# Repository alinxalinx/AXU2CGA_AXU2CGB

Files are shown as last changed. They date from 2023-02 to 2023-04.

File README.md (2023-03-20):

# Xilinx Zynq Ultrascale+ MPSoC Series Development Board AXU2CGA/AXU2CGB

## Introduction to Development Board

The PS side of the AXU2CGA mounts two DDR4 chips (totaling 1GB, 32bit) and one 256Mb QSPI FLASH. The PS side of the AXU2CGB mounts four DDR4 chips (totaling 2GB, 64bit), one 8GB eMMC FLASH memory chip, and one 256Mb FLASH memory chip
The peripheral interface of QSPI FLASH includes 1 MINI DP interface, 4 USB 3.0 interfaces, 1 Gigabit Ethernet interface, 1 USB serial port, 1 PCIE interface, 1 TF card interface, 2 40-pin expansion ports, 2 MIPI interfaces, and key LEDs. Both development boards use XCZU2CG-1SFVC784E chips.

## Key Characteristics

1. Two Micron ddr chips (AXU2CGA), four Micron ddr chips (AXU2CGB), 256MX16bit
2. One 256Mbit QUAD-SPI FLASH chip, one 8GB emmc flash chip (AXU2CGB)
3. 1 EEPROM (ps)
4. 1-channel DP output interface, mini DP (ps), maximum support 4kx2k@30fps Output
5. 4-way USB 3.0 interface, USB (ps), speed 5.0Gbps, flat USB interface (USB Type A)
6. 1-way Gigabit Ethernet interface, jl2121, connected to ps, rgmii interface
7. 1 uart to usb connection to ps
8. 1 Micro SD card holder (ps)
9. One PCIEx1 slot with a speed of 5Gbps
10. Two 40-pin expansion ports, 2.54mm spacing, one 5v, two 3.3v, three gnd, and 34 IO ports. The IO level standard of the expansion port is 3.3V
11. 1-way mipi interface (pl), 15PIN FPC connector, 2 lane data, 1 pair of clocks
12. 1 RTC real-time clock, 32.768KHz passive clock (ps)
13. Four LED lights, user indicator lights, and one reset button
14. One 4-bit dial switch, and the board supports four startup modes
15. Size 85x91.11mm
16. Power supply 12v/3A

# AXU2CGA/AXU2CGB Demo Project
## Description
This is vivado factory demo project for ALINX board.
## Requirement
* Vivado 2020.1
* AXU2CGA/AXU2CGB Development Board
## Create Vivado Project
* Download recent release ZIP archive.
* Create new project folder.
* Extract the download ZIP to the new project folder.
* For different development board, please open **\<archive extracted location\>/vivado/auto_create_project/create_project.tcl**， line 6 or 7,
Choose one projName and save.

There are two methods to create vivado project as below:
### Create Vivado Project in Vivado tcl console
1. Open Vivado software and switch to "**auto_create_project**" path with **cd** command and **Enter**
```
cd \<archive extracted location\>/vivado/auto_create_project
```
2. Type **source ./create_project.tcl** and **Enter**
```
source ./create_project.tcl
```

### Create Vivado Project using bat
1. In "**auto_create_project**" folder, there is "**create_project.bat**", open it in edit mode, and change to your own vivado software installation path. Save and close.
```
CALL E:\XilinxVitis\Vivado\2020.1\bin\vivado.bat -mode batch -source create_project.tcl
PAUSE
```
2. Double click bat file in Windows environment

For more information, please post on the [ALINX Website] (https://www.alinx.com/en).

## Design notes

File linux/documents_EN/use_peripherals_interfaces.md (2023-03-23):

[Back to Home](../)
## Use the interfaces and peripherals on the development board in LINUX

---
- These interfaces and peripherals are available on the AXU2CGA and AXU2CGB development boards: 
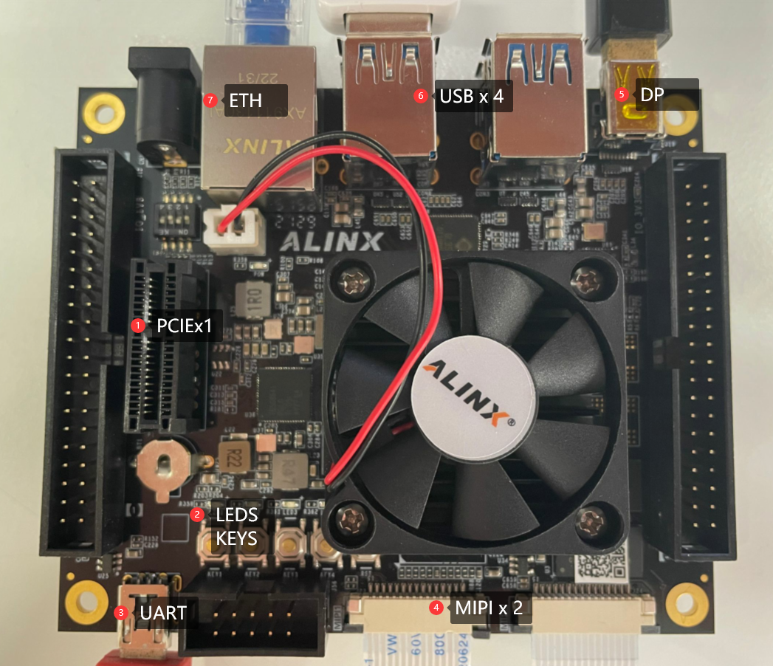
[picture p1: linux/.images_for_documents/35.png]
\
①PCIEx1\
②LEDS、KEYS\
③UART\
④MIPI x 2\
⑤DP
⑥USB x 4\
⑦ETH\
⑧EMMC(Not visible in the figure, AXU2CGB only)\
⑨EEPROM(Not visible in the figure)\
⑩QSPI FLASH(Not visible in the figure)\
⑪RTC(Not visible in the figure)\
PS : In the Linux system on the development board made earlier, I integrated some shell scripts in path *~/shells_for_testing_peripheral_devices/*, which are used to test these interfaces and peripherals. You can also refer to these shell scripts to use these interfaces and peripherals:\
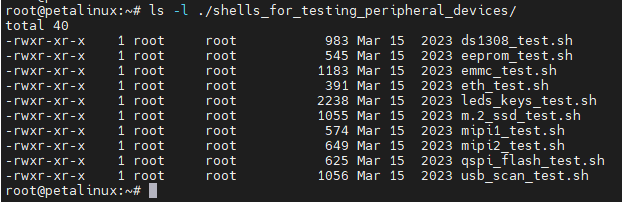
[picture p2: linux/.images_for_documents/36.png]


---
### ①PCIEx1
#### 1.1What is PCIex1
PCIe (Peripheral Component Interconnect Express) is a high-speed data transmission interface used to connect external devices and expansion cards on the motherboard. It is a serial interface. Compared with PCI interface, it has higher bandwidth and better scalability.\
PCIe slots are usually x1, x4, x8 or x16 in size, representing different bandwidth and transmission rates. The bandwidth of the PCIex1 bus interface is 250MB/s.\
PCIex1 can be used as an expansion card interface to add additional expansion cards, such as SSD controllers.
#### 1.2How to use PCIex1 in Linux
Take the SSD expansion card as an example, connect the SSD expansion card on the PCIex1 interface of the development board (please do not operate with power)：\
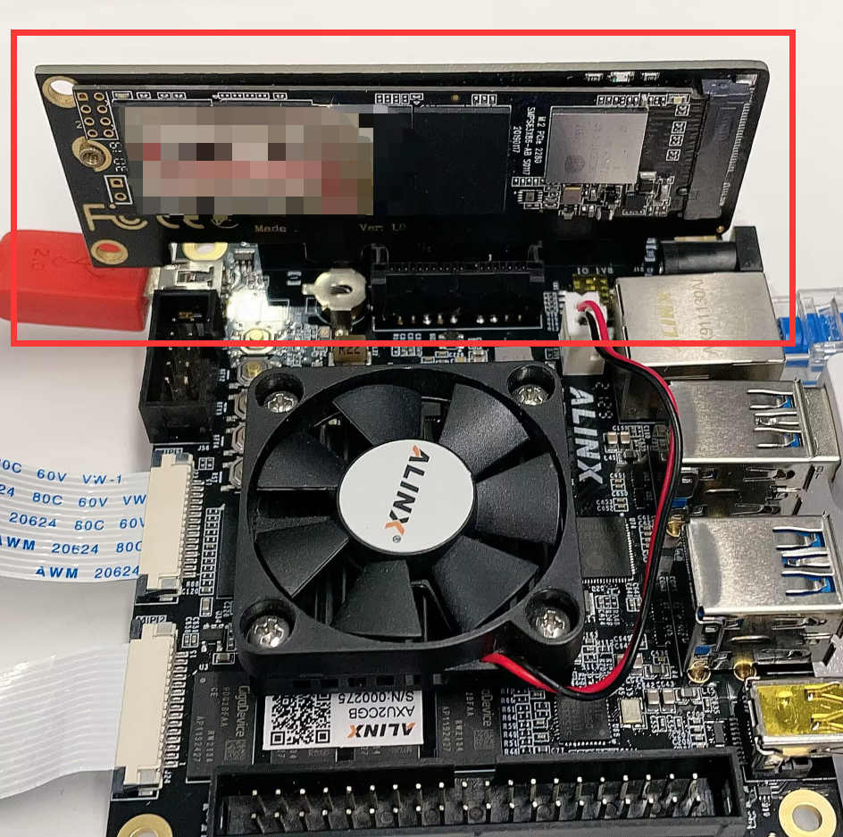
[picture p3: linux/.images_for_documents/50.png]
\
Then start the development board and log in to Linux. If  */dev/nvme0n1*  can be found, the SSD has been successfully identified.\
If the SSD has been partitioned, the device operation files corresponding to partitions like */dev/nvme0n1p1*, */dev/nvme0n1p2* can also be found.\
If the SSD does not have a partition or the file system format of the partition is not supported by the Linux system, you can use the **fdisk** tool to allocate the partition, use the **mkfs** command to make the file system, and use the mount command to mount it.\
For example, the following command will delete the first partition of */dev/nvme0n1*  and create a new partition, then format the partition into ext4 and mount it to */run/media/nvme0n1p1* :
```
#umount  partition
umount /dev/nvme0n1p1
#Delete a partition of/dev/nvme0n1 and create a new partition
echo "d

n
p
1

w
" | fdisk /dev/nvme0n1
#Format the partition /dev/nvme0n1p1 into ext4 format
echo "y

" | mkfs.ext4 /dev/nvme0n1p1
#mount /dev/nvme0n1p1 to /run/media/nvme0n1p1
mount /dev/nvme0n1p1 /run/media/nvme0n1p1
```
After mounting, you can operate on files in the mounted path, and these files will eventually be saved in the SSD.
#### 1.3Use the built-in script to test PCIex1 SSD expansion card
Run the  *m.2_ssd_test.sh*  script in  *~/shells_for_testing_peripheral_devices/* .\
\
The information will be printed differently according to the usage of your SSD, but as long as the PCIex1 interface and SSD expansion card are intact, \"*ssd read write OK* \" will be output.

---
### ②LEDS、KEYS
#### 2.1LEDs and KEYs on the development board
In addition to the RESET button, there are four groups of LEDs and KEY on the development board, all at the PL side. After power-on, the LEDs are all light by default:\
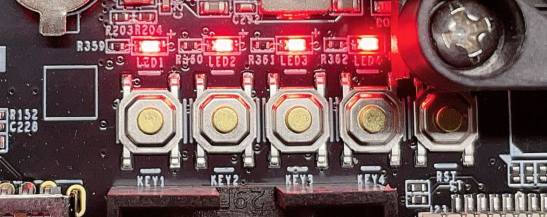
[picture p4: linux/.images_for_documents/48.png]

#### 2.2How to use LEDs and KEYs in Linux
Using LEDs and KEYs is actually configuring and using GPIO. In Linux, you only need to know the GPIO number to use the corresponding IO port. In our development version, the GPIO number of LED is from 504 to 507, and the GPIO number of KEY is from 508 to 511.\
The IO corresponding to LED needs to be configured as output. Taking LED1 as an example, the steps to use GPIO output are as follows :
```
#Export the corresponding port
echo 504 >> /sys/class/gpio/export
#Set this port as output
echo out >> /sys/class/gpio/gpio504/direction
#Make this port output high level to light LED
echo 1 >> /sys/class/gpio/gpio504/value
#Make this port output low level to turn off LED
echo 0 >> /sys/class/gpio/gpio504/value
```
The IO corresponding to KEY needs to be configured as output. Taking KEY1 as an example, the steps to use GPIO input are as follows :
```
#Export the corresponding port
echo 508 >> /sys/class/gpio/export
#Set this port as input
echo in >> /sys/class/gpio/gpio508/direction
#Read the current level state of this IO
cat /sys/class/gpio/gpio508/value
```

#### 2.3Use the built-in script to test LEDs and KEYs
Run the  *~/shells_for_testing_peripheral_devices/*  script in  *leds_keys_test.sh*  (*ps: press **ctrl+c** to exit the script.*). Then you can use KEY to control the LED to turn on or off :\


---
### ③UART
#### 3.1What is UART
UART is a communication protocol, which is called "Universal Asynchronous Receiver/Transmitter". It is a serial communication protocol that can be used to transmit data between microcontrollers, sensors, computer peripheral devices, communication devices, etc.\
UART uses two signal lines for data transmission: one is the data line (TX), which is responsible for sending data; The other is the receiving line (RX), which is responsible for receiving data. UART communication uses asynchronous transmission mode, that is, the clock signals of both sides of the communication are not synchronized, and the start bit, stop bit and parity bit need to be added in the data transmission to ensure the correctness of the data.\
The main advantages of UART are simple, flexible and widely used. Because it is a general protocol that can communicate between different devices, it is widely used in embedded systems and communication fields.
#### 3.2How to use UART in Linux
UART is used as the default terminal window for Linux in our system. Connect UART to the PC (***The driver of CP210x needs to be installed on the PC**) :\
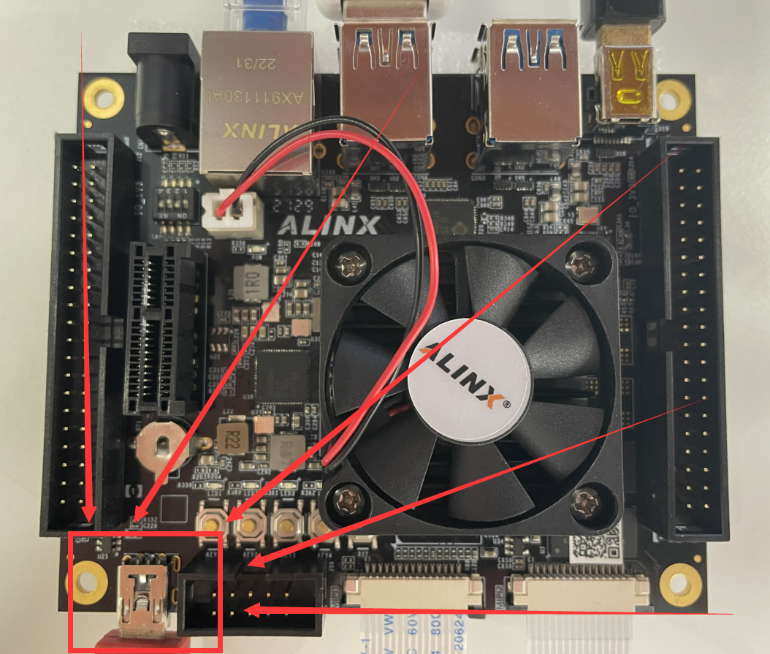
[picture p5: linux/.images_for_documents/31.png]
\
Open the corresponding COM with the serial port tool, set the baud rate to 115200, close the flow control, and click the OK button :\
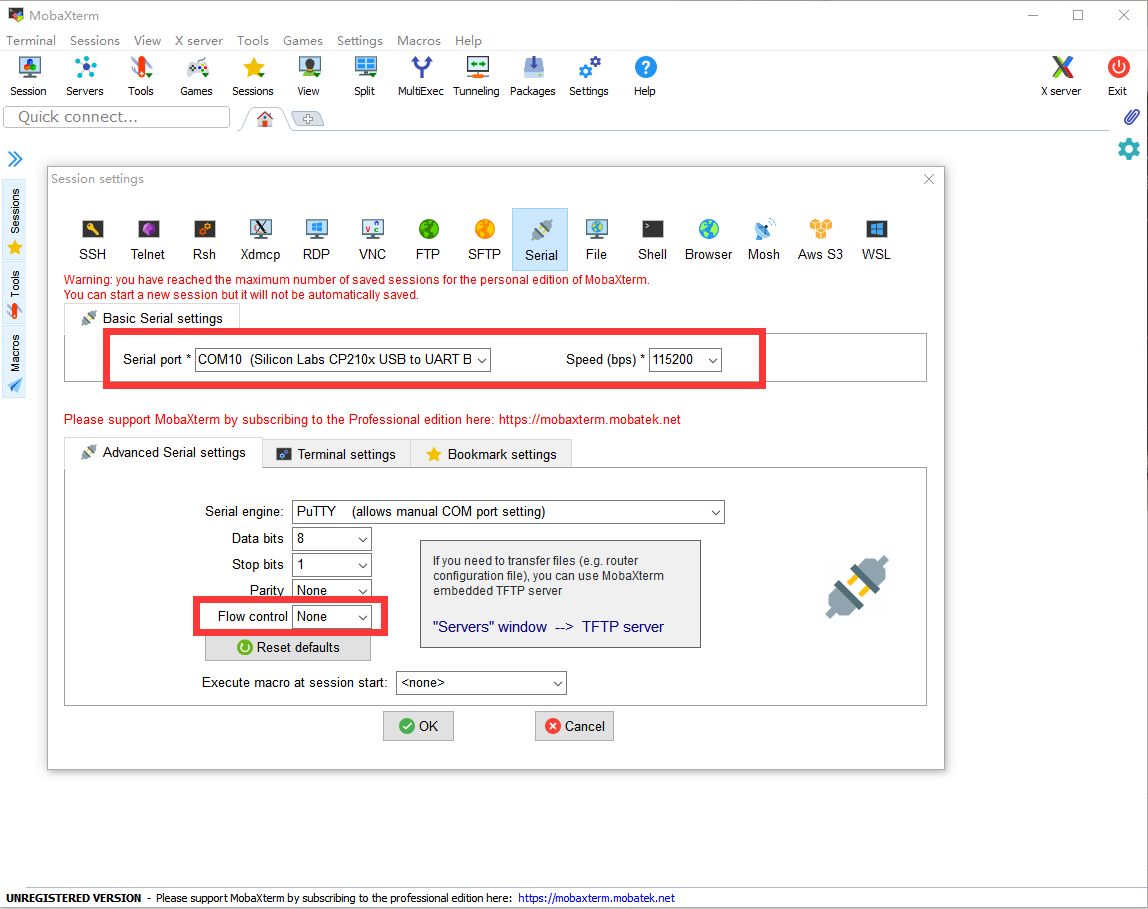
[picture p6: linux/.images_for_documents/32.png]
\
After starting the development board, you can see the print information in the serial port tool :\
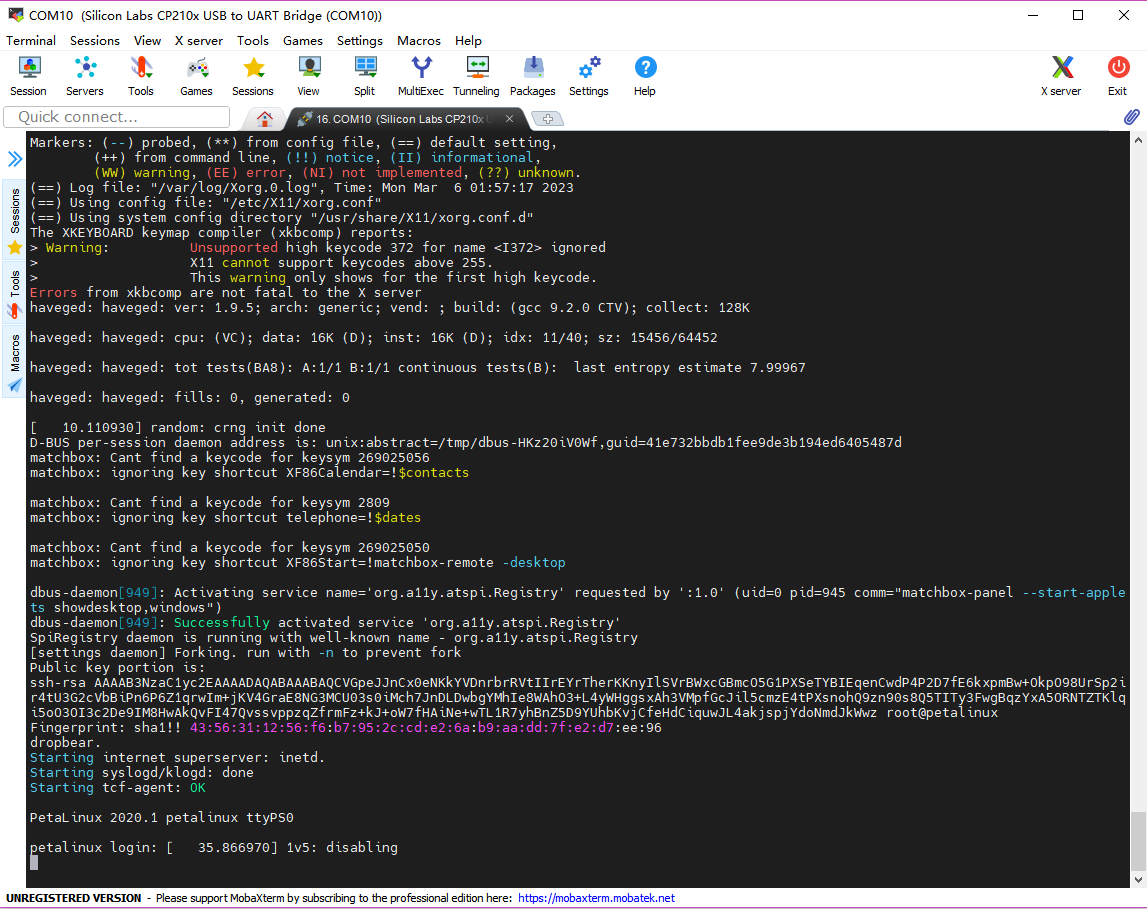
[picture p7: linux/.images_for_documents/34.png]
\
The device of UART in our Linux system is */dev/ttyPS0* . Data can be transferred through the UART interface by using the `echo "PS_UART test" > /dev/ttyPS0` command：\
\
You can see that the serial port has an echo, but the UART is used in the terminal, so it is not recommended to operate */dev/ttyPS0*.

---
### ④MIPI
#### 4.1What is MIPI
MIPI is the abbreviation of Mobile Industry Processor Interface. It is a series of interface standards developed by the MIPI Alliance, an organization created by some major mobile device manufacturers.\
MIPI is mainly committed to defining a series of hardware and software interface standards for mobile devices, including communication interfaces such as cameras, monitors and controllers, to help various parts of mobile devices exchange data and control signals more efficiently. MIPI protocol has the characteristics of high bandwidth, low power consumption, scalability, reliability and security, and is very suitable for modern mobile devices.\
In addition to mobile devices, the application of MIPI has also gradually expanded to other fields, such as automobiles, the Internet of Things, medical devices, etc., and has become one of the important interfaces for communication and control.\
The two MIPI interfaces in the current system of our development version are designed as inputs and can be connected to the MIPI camera.
#### 4.2How to use MIPI in Linux
First, we connect the monitor to the DP port and the OV5640 camera connected to the MIPI interface to the MIPI interface (please do not operate with power) :\
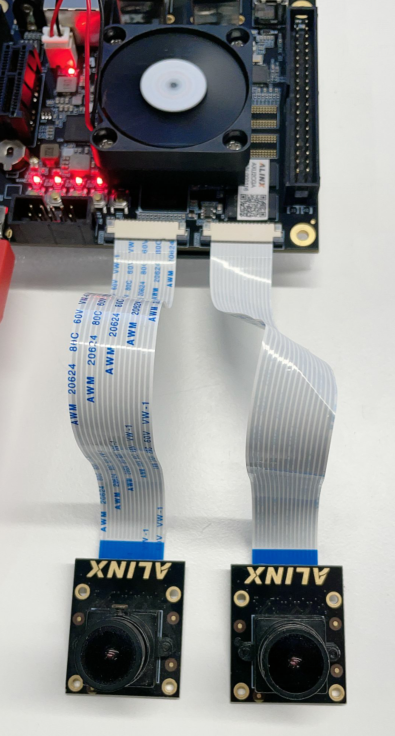
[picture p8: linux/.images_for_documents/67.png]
\
Take the MIPI1 interface as an example, use the command after the system is started and logged in :\
`media-ctl -p -d /dev/media0`\
If the node information under the device can be obtained successfully, it means that the i2c connection of the device ov5640 is normal.\
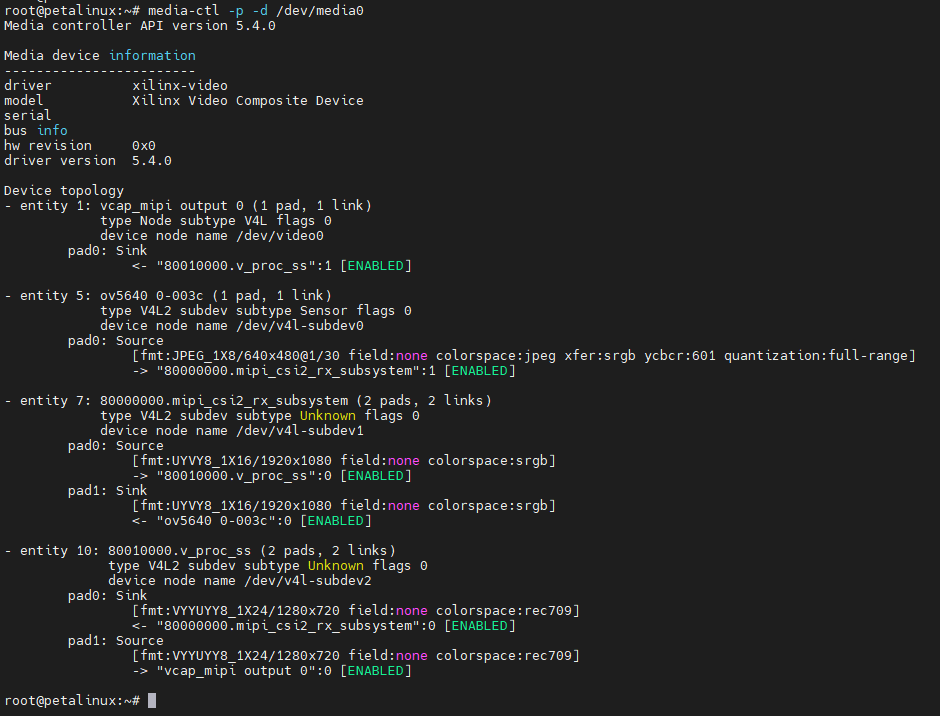
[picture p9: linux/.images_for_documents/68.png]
\
According to the above information, we can obtain the device node name as follows ：
```
ov5640 0-003c
80000000.mipi_csi2_rx_subsystem
80010000.v_proc_ss
```
Use the following command to set the camera to 1920x1080 and UYVY format ：
```
media-ctl -V '"ov5640 0-003c":0 [fmt:UYVY8_1X16/1920x1080@1/30 field:none]'
media-ctl -V '"80000000.mipi_csi2_rx_subsystem":0 [fmt:UYVY8_1X16/1920x1080 field:none]'
media-ctl -V '"80000000.mipi_csi2_rx_subsystem":1 [fmt:UYVY8_1X16/1920x1080 field:none]'
media-ctl -V '"80010000.v_proc_ss":0 [fmt:UYVY8_1X16/1920x1080 field:none]'
media-ctl -V '"80010000.v_proc_ss":1 [fmt:UYVY8_1X16/1920x1080 field:none]'
```
Then use the following command to display 1920x1080 camera image on the display :\
`gst-launch-1.0 -e v4l2src device=/dev/video0 ! video/x-raw,format=YUY2,width=1920,height=1080 ! kmssink bus-id=fd4a0000.zynqmp-display fullscreen-overlay=1`
#### 4.3Use the built-in script to test the MIPI
Connect the display to the DP port, connect the MIPI camera to the MIPI port, run the *mipi1_test.sh* or *mipi2_test.sh* scripts in  *~/shells_for_testing_peripheral_devices/* to test the two mipi interfaces respectively (*ps: press **ctrl+c** to exit the script* ). Take *mipi2_test.sh* as an example :\
\
The camera image is displayed in the display :\
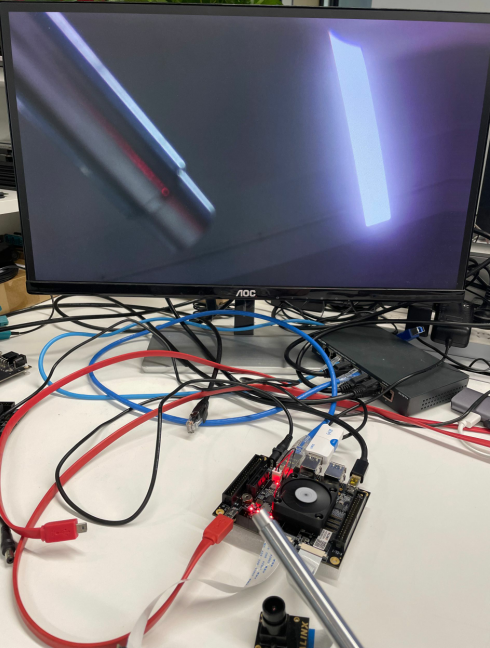
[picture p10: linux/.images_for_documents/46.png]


---
### ⑤DP
#### 5.1What is DP
DP (DisplayPort) interface is a digital video and audio interface standard used to connect computers, televisions, monitors, audio and other equipment. It is an open standard developed by Video Electronics Standards Association (VESA).\
There are two physical interfaces of DP interface, one is the standard DP interface in rectangular shape, and the other is the Mini DP interface in circular shape. The Mini DP interface is used on our development board.
#### 5.2Using DP in Linux
Connect DP to the display. After the system is started, you can see the Macthbox desktop :\
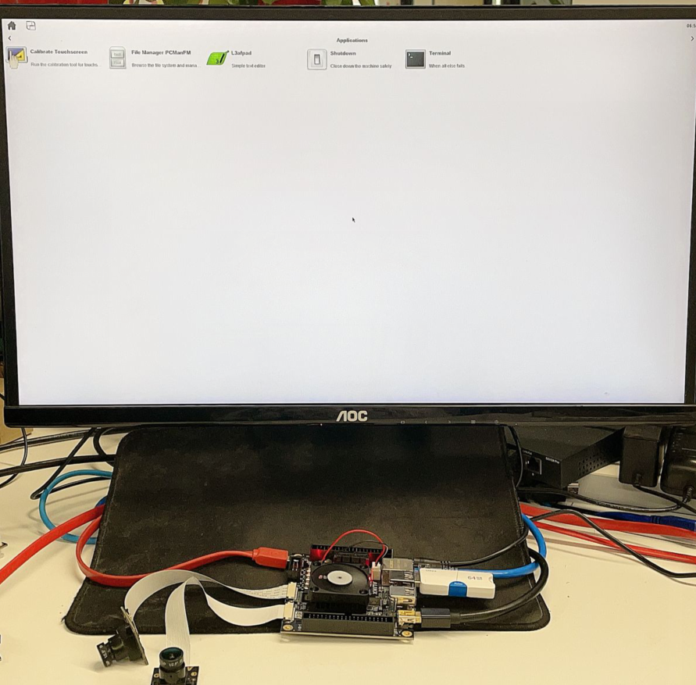
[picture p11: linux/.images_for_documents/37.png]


---
### ⑥USB x 4
#### 11.1What is USB
USB is the abbreviation of Universal Serial Bus. It is a universal data transmission standard used to connect computers or other devices with other devices, including printers, keyboards, mice, scanners, digital cameras, mobile devices and other external devices.\
With the continuous development of technology, the version of USB is also constantly updated. USB 1.0 is the earliest version and the transmission speed is very slow, but with the introduction of USB 2.0, the transmission speed has been significantly improved. USB 3.0 and USB 3.1 are faster versions, providing higher transmission speed and more power. At the same time, USB can also support different data transmission protocols, including HID (human interface device), audio, video and storage devices.\
There are four USB3.0 interfaces on our development board.
#### 11.2Using USB on Linux systems
In fact, common USB devices can be used directly on this system. For example, the mouse and keyboard can be used directly with the desktop. If you use the storage tools such as USB flash disk, you need to pay attention to the partition and file system format. You can refer to the partition and format method of SSD in **①PCIEx1**. After the USB flash disk is connected to the system, the device operation files are generally */dev/sda1*, */dev/sda2*, etc.
#### 11.3 script in Linux to test USB Drive
Connect a USB2.0 device (such as a mouse) and a USB3.0 device (such as a 3.0 USB flash drive) respectively, and use the *usb_scan_test.sh* script in *~/shells_for_testing_peripheral_devices/* to check whether the current four USB ports are intact, and check the connection of USB2.0 and USB3.0 devices.

---
### ⑦ETH
#### 7.1What is ETH
In the Linux operating system, \"ETH\" usually refers to the network interface device, which is the hardware device used to communicate between the computer and the network. In Linux, you can use the *ifconfig* command to manage and configure network interface devices. The development board and other network devices can be connected in the same network through the ETH interface for data transmission.\
In the Ethernet protocol, each device is assigned a unique MAC address for identification and communication in the network. When computers send data through network interface devices, they will be encapsulated in Ethernet frames and routed and transmitted using MAC addresses.
#### 7.2Using ETH in Linux
Connect ETH (such as through router or switch) to LAN :\
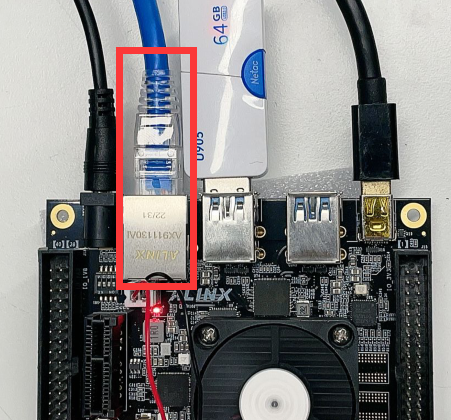
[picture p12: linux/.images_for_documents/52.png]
\
Then power on the development board, log in to the system, and use *ifconfig* to view the current ETH status :\
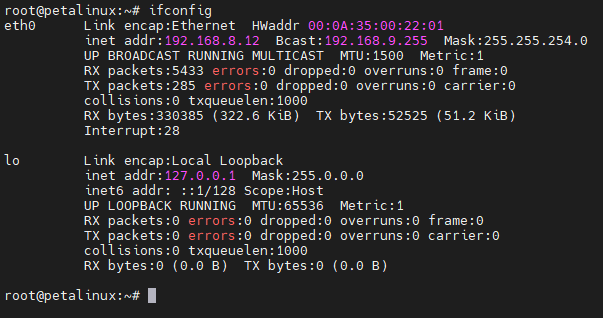
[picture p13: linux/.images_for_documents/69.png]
\
If your router or switch supports DHCP, both eth0 and eth1 will be automatically connected and be assigned an IP address.\
If no IP address is assigned, you need to use the following command to assign it manually, for example :\
`ifconfig eth0 192.168.8.67`\
The *ifconfig* command can also be used to set the subnet mask; If the MAC address needs to be modified, */etc/network/interfaces* needs to be modified; If you want to set the gateway, you need to use command **route**; If you need to modify DNS, you need to modify */etc/resolv.conf*. The relevant configuration will not be detailed, generally, as long as you connect to the LAN through the network cable, you can use eth0 directly after the system is powered on.\
#### 7.3Use the built-in script to set up and test ETH
Run the *eth_test.sh*  script in *~/shells_for_testing_peripheral_devices/*. This script can be followed by a parameter, that is, the address you want to ping. For example, here I ping www.baidu.com. If no parameter is added, the default is ping *www.google.com* :\
\
Finally, the result of the ping and the speed of the network interface link will be print.

---
### ⑧EMMC(AXU2CGB ONLY)
#### 8.1What is EMMC
EMMC (Embedded MultiMediaCard) is a storage device widely used by embedded devices. It integrates flash memory chip, controller, host interface and flash memory management software into a small package. With its small size, low power consumption and high cost performance, eMMC is a common choice in embedded device storage solutions.\
EMMC is mainly used in mobile devices (such as smart phones, tablets, digital cameras, etc.) and embedded devices in automotive, industrial control and other fields. It provides a high-speed and reliable storage solution, supports fast startup and data reading and writing, and can store operating system, application programs, media files and other data.\
An 8G EMMC is integrated on our development board.
#### 8.2Using EMMC on Linux
The operation file of EMMC in Linux system is */dev/mmcblk0*. The use method is similar to that of SSD in **⑧M.2** : set the partition, format the partition, and finally mount the partition. for example :
```
#Unmount partition
umount /dev/mmcblk0p1
#Delete a partition of /dev/mmcblk0 and create a new partition
echo "d

n
p
1

w
" | fdisk /dev/mmcblk0
#Format the /dev/mmcblk0p1 partition into ext4 format
echo "y

" | mkfs.ext4 /dev/mmcblk0p1
#mount /dev/mmcblk0p1 on /media/sd-mmcblk0p1
mount /dev/mmcblk0p1 /media/sd-mmcblk0p1
```
After mounting, you can operate on files in the mounted path, and these files will eventually be saved in EMMC.
#### 8.3Use the built-in script in Linux to test EMMC
Run the *emmc_test.sh* script in *~/shells_for_testing_peripheral_devices/*  :\


---
### ⑨EEPROM
#### 9.1What is EEPROM
EEPROM is a non-volatile memory (NVM), which is an improved version of the electrically erasable programmable read-only memory (EPROM). EEPROM can be erased and programmed by electronic signals.\
EEPROM is usually used to store a small amount of data, such as configuration information on the chip, product serial number, encryption key, etc. In some electronic devices, EEPROM can also be used to store user settings and personal data.\
Compared with flash memory, EEPROM has faster reading speed and higher durability, but smaller capacity. Compared with DRAM, EEPROM has longer data retention time, but slower write speed.
#### 9.2Using EEPROM on Linux
The operating file of eeprom in the system is */sys/bus/i2c/devices/1-0050/eeprom*.\
Use the following command to write data to eeprom :\
`echo -e "test e2prom\n" > /sys/bus/i2c/devices/1-0050/eeprom`\
Use the following command to view the contents of eeprom :\
`cat /sys/bus/i2c/devices/1-0050/eeprom`\

#### 9.3Use the built-in script in Linux to test EEPROM
Run the *eeprom_test.sh* script in *~/shells_for_testing_peripheral_devices/*  :\


---
### ⑩QSPI FLASH
#### 10.1What is QSPI FLASH
Flash is a kind of high-speed flash memory, which is often used in embedded systems and other applications to store program code, configuration data and other information.\
QSPI Flash is a flash chip based on SPI interface. It communicates through four parallel data lines (quad interfaces). Compared with traditional SPI Flash, it can achieve faster data transmission speed, usually up to tens of MHz. The capacity of QSPI Flash is usually between a few megabytes and tens of megabytes.\
QSPI Flash has many advantages, including fast read and write speed, low power consumption, erasability, easy integration and use, etc. In addition, it can be programmed and erased by software without any external equipment or signal line.
#### 10.2Using QSPI FLASH on Linux systems
In the current Linux system, QSPI FLASH is used to store the environment variables of u-boot. If you modify the environment variables of u-boot, you need to be careful when operating QSPI FLASH.
The operation file of QSPI FLASH in the system is */dev/mtd0*.
The FLASH device needs to be erased before writing. Use the following command to erase the first sector of QSPI FLASH :\
`flash_erase /dev/mtd0 0 1`\
*/dev/mtd0* is a block device. You can use the **dd** command to read or write files to */dev/mtd0*.\
Write the file to */dev/mtd0 with the following command* :
```
touch /home/root/.qspiflashwrite
echo "qspiflash test" > /home/root/.qspiflashwrite
dd of=/dev/mtd0 if=/home/root/.qspiflashwrite bs=4096 count=1
```
Use the following command to read data from */dev/mtd0* to a file :
```
touch /home/root/.qspiflashread
dd if=/dev/mtd0 of=/home/root/.qspiflashread  bs=4096 count=1
```
#### 10.3Use the built-in script in Linux to test QSPI FLASH
Run the *qspi_flash_test.sh* script in *~/shells_for_testing_peripheral_devices/*  :\


---
### ⑪RTC
#### 11.1What is RTC
The Real Time Clock (RTC) unit provides an accurate time reference for the entire system and application software.
#### 11.2Using RTC on Linux systems
In our Linux system, the device operation file of RTC is */dev/rtc0*. You can use the **hwclock** command to read and write */dev/rtc0*. For example:
```
#Set the system time to "2023-03-01 10:30:00"
date --set="2023-03-01 10:30:00"
#Write the system time to/dev/rtc0
hwclock -f /dev/rtc0 -w
#Update the system time with the time in /dev/rtc0
hwclock -f /dev/rtc0 -r
```

#### 11.3Use the built-in script in Linux to test RTC
Run the *ds1308_test.sh* script in *~/shells_for_testing_peripheral_devices/* :\


---
---
- Visit [ALINX official website](https://www.alinx.com) for more information.

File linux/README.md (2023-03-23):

# Run Linux on Series Development Boards : AXU2CGA, AXU2CGB / 在系列开发板：AXU2CGA, AXU2CGB上使用Linux
---
---
## Content in this path / 本路径中的内容 
	│
	└─── linux
		│
		├── hardware
		│	│
		│	├── AXU2CGA 
		│	│	│
		│	│	└─ design_1_wrapper.xsa	
		│	│
		│	└── AXU2CGB 
		│	 	│
		│	 	└─ design_1_wrapper.xsa	
		│
		├── petalinux
		│
		├── documents_EN
		│	│
		│	├──  make_sd_for_runnging_linux.md	
		│	│
		│	├──  use_petalinux_to_make_linux.md	
		│	│
		│	└──  use_peripherals_interfaces.md
		│
		├── documents_CN
		│	│
		│	├──  make_sd_for_runnging_linux.md	
		│	│
		│	├──  use_petalinux_to_make_linux.md
		│	│
		│	└──  use_peripherals_interfaces.md
		│
		├── auto_config_petalinux_hardware.sh
		│
		├── set_offline_sstate_and_downloads.sh
		│
		└── README.md
---
---
## Documentation Guidelines
- If you want to quickly start a Linux on the development board, please refer to [make_sd_for_runnging_linux.md](./documents_EN/make_sd_for_runnging_linux.md).
- If you want to use Petalinux tool to configure the petalinux project we provide, please refer to [use_petalinux_to_make_linux.md](./documents_EN/use_petalinux_to_make_linux.md).
- If you have successfully started Linux on the development board, and now want to know what interfaces are on the development board and how to use them, please refer to [use_peripherals_interfaces.md](./documents_EN/use_peripherals_interfaces.md).
## 文档指引
- 如果你想快速在开发板上启动Linux，请参考[make_sd_for_runnging_linux.md](./documents_CN/make_sd_for_runnging_linux.md)。
- 如果你想用Petalinux工具来配置我们提供的petalinux工程，请参考[use_petalinux_to_make_linux.md](./documents_CN/use_petalinux_to_make_linux.md)。
- 如果你已经成功在开发板上启动了Linux，现在想知道开发板上有哪些接口以及如何使用，请参考[use_peripherals_interfaces.md](./documents_CN/use_peripherals_interfaces.md)。
---
---
- Visit [ALINX Official Website](https://www.alinx.com) for more information.
- 访问[ALINX官方网站](https://www.alinx.com)以获取更多信息。

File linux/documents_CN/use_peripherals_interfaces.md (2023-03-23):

[返回首页](../)
## 在LINUX中使用开发板上的接口和外设

---
- AXU2CGA、AXU2CGB开发板上有这些接口和外设：\
\
①PCIEx1\
②LEDS、KEYS\
③UART\
④MIPI x 2\
⑤DP
⑥USB x 4\
⑦ETH\
⑧EMMC(图中不可见，仅AXU2CGB)\
⑨EEPROM(图中不可见)\
⑩QSPI FLASH(图中不可见)\
⑪RTC(图中不可见)\
PS：在前面制作的开发板上的Linux系统中，我集成了一些脚本在 *~/shells_for_testing_peripheral_devices/* 路径中用于测试这些接口和外设，你也可以参考这些脚本来使用这些接口和外设：\


---
### ①PCIEx1
#### 1.1什么是PCIex1
PCIe（Peripheral Component Interconnect Express）是一种高速数据传输接口，用于连接主板上的外部设备和扩展卡。它是一种串行接口，与PCI接口相比，具有更高的带宽和更好的可扩展性。\
PCIe插槽的大小通常为x1、x4、x8或x16，分别代表着不同的带宽和传输速率。PCIex1总线接口的带宽为250MB/s。\
PCIex1可以作为扩展卡接口，用于添加额外的扩展卡，例如SSD控制器。
#### 1.2在Linux中使用PCIex1
以SSD扩展卡为例，在开发板的PCIex1接口上接上SSD扩展卡(请不要带电操作)：\
\
然后启动开发板，登录Linux，如果能找到 */dev/nvme0n1* 说明SSD已经成功被识别到了。\
如果这个SSD已经被分过区了，那么还能找到 */dev/nvme0n1p1*, */dev/nvme0n1p2* 等分区对应的设备操作文件。\
如果SSD没有分区或者分区的文件系统格式Linux系统不支持，可以使用**fdisk**工具来分配分区，使用**mkfs**命令制作文件系统以及使用mount命令挂载。\
例如下面的命令将会删除 */dev/nvme0n1* 的第一个分区并新建一个分区，再把这个分格式化成ext4并挂载到 */run/media/nvme0n1p1* ：
```
#解挂分区
umount /dev/nvme0n1p1
#删除/dev/nvme0n1的一个分区并新建一个分区
echo "d

n
p
1

w
" | fdisk /dev/nvme0n1
#把/dev/nvme0n1p1分区格式化成ext4格式
echo "y

" | mkfs.ext4 /dev/nvme0n1p1
#挂载/dev/nvme0n1p1到/run/media/nvme0n1p1
mount /dev/nvme0n1p1 /run/media/nvme0n1p1
```
挂载之后，就可以在挂载的路径中操作文件了，而这些文件最终都会被保存在SSD中。
#### 1.3使用系统内置的脚本测试PCIex1 SSD扩展卡
运行 *~/shells_for_testing_peripheral_devices/* 中的 *m.2_ssd_test.sh* 脚本：\
\
根据你的SSD的使用情况会用不同打印信息，但只要PCIex1接口和SSD扩展卡是完好的最终肯定会输出\"*ssd read write OK* \"。

---
### ②LEDS、KEYS
#### 2.1开发板上的LEDs和KEYs
除了RESET按钮之外，开发板上有四组LED和KEY，都在PL端。上电后LED默认是全部点亮的：\

#### 2.2在Linux中使用LEDs和KEYs
使用LEDs和KEYs实际上就是配置和使用GPIO，在Linux中只需要知道GPIO号就可以使用对应的IO口。在我们的开发版上，LED的GPIO号是从504到507，KEY的GPIO号是从508到511。\
LED对应的IO需要配置成输出，以LED1为例，使用GPIO输出的步骤如下：
```
#导出对应的端口
echo 504 >> /sys/class/gpio/export
#设置这个端口为输出
echo out >> /sys/class/gpio/gpio504/direction
#使这个端口输出高电平，点亮LED
echo 1 >> /sys/class/gpio/gpio504/value
#使这个端口输出低电平，熄灭LED
echo 0 >> /sys/class/gpio/gpio504/value
```
KEY对应的IO需要配置成输出，以KEY1为例，使用GPIO输入的步骤如下：
```
#导出对应的端口
echo 508 >> /sys/class/gpio/export
#设置这个端口为输入
echo in >> /sys/class/gpio/gpio508/direction
#读取这个IO当前的电平状态
cat /sys/class/gpio/gpio508/value
```

#### 2.3使用系统内置的脚本测试LEDs和KEYs
运行 *~/shells_for_testing_peripheral_devices/* 中的 *leds_keys_test.sh* 脚本(*ps：按**ctrl+c**组合键退出该脚本。*)。然后可以用KEY控制LED点亮和熄灭：\


---
### ③UART
#### 3.1什么是UART
UART是一种通信协议，全称为“通用异步收发传输器”（Universal Asynchronous Receiver/Transmitter）。它是一种串行通信协议，可以用于在微控制器、传感器、电脑周边设备、通信设备等之间传输数据。\
UART使用两根信号线来进行数据传输：一根是数据线（TX），负责发送数据；另一根是接收线（RX），负责接收数据。UART通信使用异步传输方式，也就是说，通信双方的时钟信号不同步，需要在数据传输中加入起始位、停止位和奇偶校验位来保证数据的正确性。\
UART的主要优点是简单、灵活和广泛使用。由于它是一种通用协议，可以在各种不同的设备之间进行通信，因此在嵌入式系统和通信领域中应用广泛。\
#### 3.2在Linux中使用UART
UART在我们制作的系统中用于Linux的默认终端窗口，把UART连接到PC(***PC上需要安装CP210x的驱动***)：\
\
用串口工具打开对应的COM，设置波特率设置为115200，关闭流控制，点击OK按钮：\
\
启动开发板后可以看到串口工具中打印信息：\
\
UART在我们制作的Linux系统中的设备是 */dev/ttyPS0* ，使用`echo "PS_UART test" > /dev/ttyPS0`命令可以通过UART接口传输数据：\
\
可以看到串口有回显，但是UART被用于终端窗口，因此不建议对 */dev/ttyPS0* 进行操作。

---
### ④MIPI
#### 4.1什么是MIPI
MIPI是移动行业处理器接口(Mobile Industry Processor Interface)的缩写，是由一些主要移动设备制造商创建的组织MIPI联盟所制定的一系列接口标准。\
MIPI主要致力于定义一系列用于移动设备的硬件和软件接口标准，包括像相机、显示器、控制器等通信接口，以帮助移动设备的各个部分之间更高效地交换数据和控制信号。MIPI协议具有高带宽、低功耗、可扩展性、可靠性和安全性等特点，非常适用于现代移动设备。\
除了移动设备，MIPI的应用还逐渐扩展到了其他领域，如汽车、物联网、医疗设备等，成为了通信和控制的重要接口之一。\
我们开发版当前系统的系统中两个MIPI接口都被设计成了输入，可以连接MIPI摄像头使用。
#### 4.2在Linux中使用MIPI
首先我们连接显示器到DP口并接入MIPI接口的OV5640摄像头到MIPI接口(请不要带电操作)：\
\
以MIPI1接口为例，在系统启动并登录后使用命令：\
`media-ctl -p -d /dev/media0`\
如果可以成功获取设备下各节点信息，则说明设备ov5640的i2c连接正常。\
\
根据上面的信息，我们可以获取到设备节点名如下：
```
ov5640 0-003c
80000000.mipi_csi2_rx_subsystem
80010000.v_proc_ss
```
使用下面的命令设置摄像头为1920x1080、UYVY格式：
```
media-ctl -V '"ov5640 0-003c":0 [fmt:UYVY8_1X16/1920x1080@1/30 field:none]'
media-ctl -V '"80000000.mipi_csi2_rx_subsystem":0 [fmt:UYVY8_1X16/1920x1080 field:none]'
media-ctl -V '"80000000.mipi_csi2_rx_subsystem":1 [fmt:UYVY8_1X16/1920x1080 field:none]'
media-ctl -V '"80010000.v_proc_ss":0 [fmt:UYVY8_1X16/1920x1080 field:none]'
media-ctl -V '"80010000.v_proc_ss":1 [fmt:UYVY8_1X16/1920x1080 field:none]'
```
然后使用下面的命令在显示器上显示1920x1080的摄像头图像：\
`gst-launch-1.0 -e v4l2src device=/dev/video0 ! video/x-raw,format=YUY2,width=1920,height=1080 ! kmssink bus-id=fd4a0000.zynqmp-display fullscreen-overlay=1`
#### 4.3使用系统内置的脚本测试MIPI
连接显示器到DP口，连接MIPI摄像头到MIPI口，运行 *~/shells_for_testing_peripheral_devices/* 中的 *mipi1_test.sh* 和*mipi2_test.sh*  脚本分别测试两个mipi接口(*ps：按**ctrl+c**组合键退出该脚本。*)以*mipi2_test.sh*  为例：\
\
显示器中显示摄像头图像：\


---
### ⑤DP
#### 5.1什么是DP
DP (DisplayPort) 接口是一种数字视频和音频接口标准，用于连接计算机、电视、显示器、音响等设备。它是一种开放标准，由 Video Electronics Standards Association (VESA) 组织制定。\
DP 接口的物理接口有两种，一种是矩形形状的标准 DP 接口，另一种是圆形形状的 Mini DP 接口。我们的开发板上使用的就是Mini DP接口。
#### 5.2在Linux中使用DP
把DP连接到显示器上即可，系统启动后可以看到Macthbox的桌面：\


---
### ⑥USB x 4
#### 6.1什么是USB
USB是Universal Serial Bus的缩写，它是一种通用的数据传输标准，用于将计算机或其他设备与其他设备连接，包括打印机、键盘、鼠标、扫描仪、数字相机、移动设备和其他各种外部设备。\
随着技术的不断发展，USB的版本也在不断更新。USB 1.0是最早的版本，传输速度很慢，但是随着USB 2.0的推出，传输速度得到了显著提高。USB 3.0和USB 3.1是更快的版本，提供更高的传输速度和更多的功率。同时，USB还可以支持不同的数据传输协议，包括HID（人体接口设备）、音频、视频和存储设备等。\
我们的开发板上有四个USB3.0接口。
#### 6.2在Linux系统上使用USB
实际上常用USB设备都可以直接在这个系统上使用。比如鼠标键盘，都可以直接配合桌面来使用。使用U盘这些存储工具的话则需要注意分区和文件系统格式，可以参考**①PCIEx1**中SSD的分区和格式化方法。U盘接入到系统之后，设备操作文件一般是 */dev/sda1* 、  */dev/sda2* 等等。
#### 6.3使用系统内置的脚本测试USB
分别接入一个USB2.0设备（比如鼠标）和一个USB3.0设备（比如3.0的U盘），使用 *~/shells_for_testing_peripheral_devices/* 中的 *usb_scan_test.sh* 脚本，可以检测当前USB四个口是否完好，并检测USB2.0和USB3.0设备的连接情况。

---
### ⑦ETH
#### 7.1什么是ETH
在Linux操作系统中，\"ETH\" 通常指的是网络接口设备，它是用于在计算机与网络之间进行通信的硬件设备。在Linux中，可以使用 *ifconfig* 命令来管理和配置网络接口设备。可以通过ETH接口把开发板和其他网络设备连接在同一网络中，以便进行数据传输。\
在以太网协议中，每个设备都被分配一个唯一的MAC地址，以便在网络中进行识别和通信。当计算机通过网络接口设备发送数据时，它们将被封装在以太网帧中，并使用MAC地址进行路由和传输。
#### 7.2在Linux中使用ETH
连接ETH(比如通过路由器或交换机)到局域网：\
\
然后开发板上电，登陆系统，使用 *ifconfig* 可以查看当前ETH的状态：\
\
如果你的路由器或交换机支持DHCP，eth0和eth1都会自动连接并分配到ip。\
如果没有被分配ip则需要用下面的命令来手动分配，例如：\
`ifconfig eth0 192.168.8.67`\
*ifconfig* 命令还可以用来设置子网掩码；如果需要修改MAC地址则需要修改 */etc/network/interfaces* ；如果要设置网关则需要用到**route**命令；如果需要修改DNS则需要修改 */etc/resolv.conf* ，相关的配置就不详细讲了，一般来说只要通过网线连接到局域网，系统上电之后就可以直接使用eth0了。
#### 7.3使用系统内置的脚本设置并测试ETH
运行 *~/shells_for_testing_peripheral_devices/* 中的 *eth_test.sh* 脚本，这个脚本后可以带一个参数，即你想ping的地址，比如这里我ping了一下百度，如果不加参数则默认ping *www.google.com* ：\
\
最后会显示ping的结果和网口link的速度。

---
### ⑧EMMC(仅AXU2CGB)
#### 8.1什么是EMMC
eMMC（Embedded MultiMediaCard）是一种被嵌入式设备广泛采用的存储器件，它将闪存芯片、控制器、主机接口和闪存管理软件集成在一个小型封装中。eMMC的体积小、功耗低、性价比高，是嵌入式设备存储方案中的一种常见选择。\
eMMC主要应用于移动设备（例如智能手机、平板电脑、数字相机等）以及汽车、工业控制等领域的嵌入式设备中。它提供了一种高速、可靠的存储解决方案，支持快速启动和数据读写，可以存储操作系统、应用程序、媒体文件等数据。
#### 8.2在Linux系统上使用EMMC
EMMC在Linux系统中的操作文件是 */dev/mmcblk0* ，使用方法和**①PCIEx1**中SSD的使用方法类似：设置分区并格式化分区最后挂载分区。例如：
```
#解挂分区
umount /dev/mmcblk0p1
#删除/dev/mmcblk0的一个分区并新建一个分区
echo "d

n
p
1

w
" | fdisk /dev/mmcblk0
#把/dev/mmcblk0p1分区格式化成ext4格式
echo "y

" | mkfs.ext4 /dev/mmcblk0p1
#挂载/dev/mmcblk0p1到/media/sd-mmcblk0p1
mount /dev/mmcblk0p1 /media/sd-mmcblk0p1
```
挂载之后，就可以在挂载的路径中操作文件了，而这些文件最终都会被保存在EMMC中。
#### 8.3使用系统内置的脚本测试EMMC
运行 *~/shells_for_testing_peripheral_devices/* 中的 *emmc_test.sh* 脚本：\


---
### ⑨EEPROM
#### 9.1什么是EEPROM
EEPROM是一种非易失性存储器（NVM），它是电可擦可编程只读存储器（EPROM）的改进版本。EEPROM可以通过电子信号进行擦除和编程。\
EEPROM通常用于存储小量的数据，例如芯片上的配置信息、产品序列号、加密密钥等。在一些电子设备中，EEPROM还可以用来存储用户设置和个人资料等数据。\
与闪存相比，EEPROM具有更快的读取速度和更高的耐用性，但容量较小。与DRAM相比，EEPROM具有更长的数据保持时间，但写入速度较慢。
#### 9.2在Linux系统上使用EEPROM
eeprom在系统中的操作文件是 */sys/bus/i2c/devices/2-0050/eeprom* 。\
使用命令：\
`echo -e "test e2prom\n" > /sys/bus/i2c/devices/2-0050/eeprom`\
可以往eeprom中写入引号中的数据。\
使用命令：\
`cat /sys/bus/i2c/devices/2-0050/eeprom`\
可以查看eeprom中的内容。\

#### 9.3使用系统内置的脚本测试EEPROM
运行 *~/shells_for_testing_peripheral_devices/* 中的 *eeprom_test.sh* 脚本：\


---
### ⑩QSPI FLASH
#### 10.1什么是QSPI FLASH
Flash是一种高速闪存存储器，常用于嵌入式系统和其他应用中，用于存储程序代码、配置数据和其他信息。\
QSPI Flash是一种基于SPI接口的闪存芯片，它通过四个并行数据线（quad interface）进行通信，与传统的SPI Flash相比，可以实现更快的数据传输速度，通常达到几十MHz的传输速度。QSPI Flash的容量通常在几兆字节到几十兆字节之间。\
QSPI Flash具有许多优点，包括快速读写速度、低功耗、可擦写性、易于集成和使用等。此外，它还可以通过软件进行编程和擦除，而无需任何外部设备或信号线。
#### 10.2在Linux系统上使用QSPI FLASH
在当前的Linux系统中QSPI FLASH被用于存储u-boot的环境变量，如果修改了u-boot的环境变量那么操作QSPI FLASH就需要小心了。\
QSPI FLASH在系统中的操作文件是 */dev/mtd0*。\
FLASH设备在写之前需要先擦，使用下面的命令可以擦除QSPI FLASH的第一个扇区：\
`flash_erase /dev/mtd0 0 1`\
*/dev/mtd0* 是块设备，可以用**dd**命令来读写文件到 */dev/mtd0*。\
用下面的命令写文件到 */dev/mtd0* ：
```
touch /home/root/.qspiflashwrite
echo "qspiflash test" > /home/root/.qspiflashwrite
dd of=/dev/mtd0 if=/home/root/.qspiflashwrite bs=4096 count=1
```
用下面的命令从 */dev/mtd0* 读取数据到文件：
```
touch /home/root/.qspiflashread
dd if=/dev/mtd0 of=/home/root/.qspiflashread  bs=4096 count=1
```
#### 10.3使用系统内置的脚本测试QSPI FLASH
运行 *~/shells_for_testing_peripheral_devices/* 中的 *qspi_flash_test.sh* 脚本：\


---
### ⑪RTC
#### 11.1什么是RTC
实时时钟(RTC)单元为整个系统和应用软件提供了一个精确的时间基准。
#### 11.2在Linux系统上使用RTC
在我们的Linux系统中，RTC的设备操作文件是 */dev/rtc0*。可以用**hwclock**命令来读写 */dev/rtc0*。例如：
```
#设置系统时间为"2023-03-01 10:30:00"
date --set="2023-03-01 10:30:00"
#把系统时间写入到/dev/rtc0
hwclock -f /dev/rtc0 -w
#用/dev/rtc0中的时间更新系统时间
hwclock -f /dev/rtc0 -r
```

#### 11.3使用系统内置的脚本测试RTC
运行 *~/shells_for_testing_peripheral_devices/* 中的 *ds1308_test.sh* 脚本：\


---
---
- 访问[ALINX官方网站](https://www.alinx.com)以获取更多信息。

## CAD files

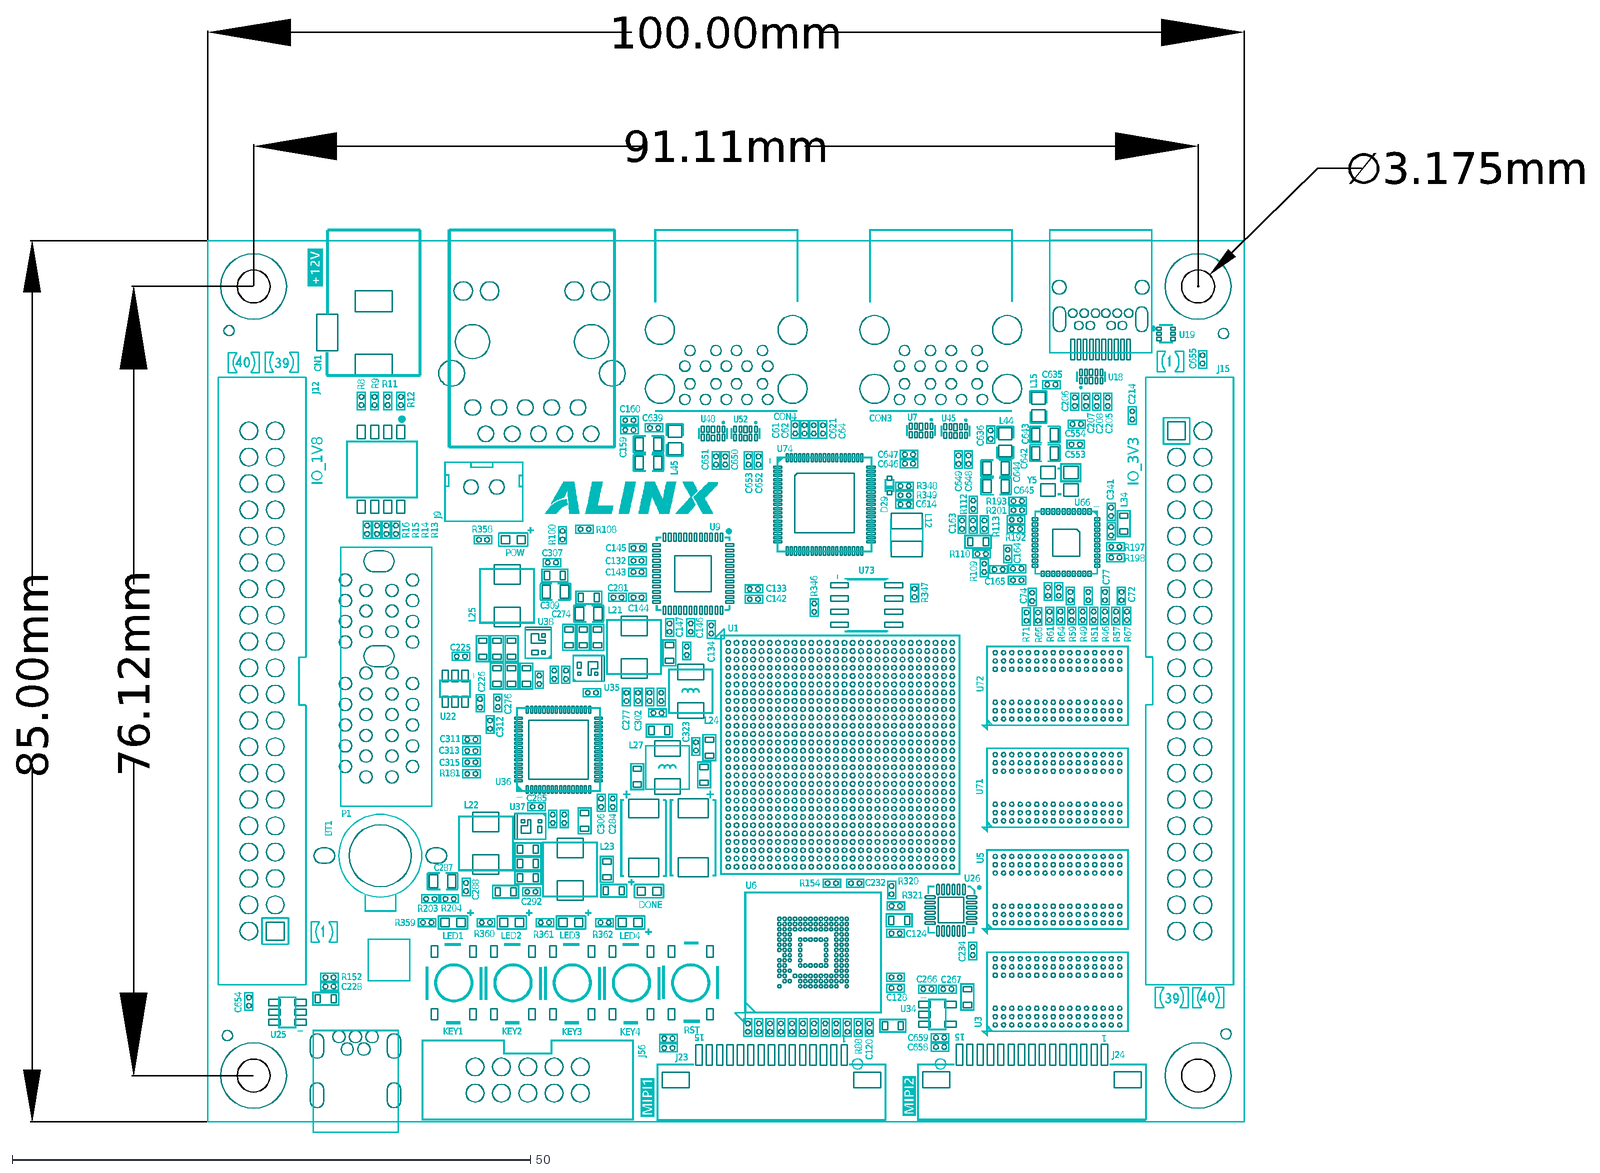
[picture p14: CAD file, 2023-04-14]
hardware/STEP_Models/AXU2CG_size_structure.dxf
J15
J12
U18
U48
U52
U45
U7
C309
C287
C274
C642
C643
C644
C645
J56
15
1
J24
J23
U3
U5
U71
U72
R346
R347
R348
R349
R201
R100
R11
R12
R8
R9
R108
R109
R110
R113
R192
R193
R197
R198
R112
R152
R88
R13
R14
R15
R16
R154
R181
R46
R49
R51
R57
R59
R61
R64
R66
R67
R71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

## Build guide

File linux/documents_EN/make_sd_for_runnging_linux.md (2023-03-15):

[Back to Home](../)
## Start the linux on the development board from the SD card

---
### 1.Adjust the dial switch
Adjust the dial switch on the development board to the state of starting from the SD card, as shown below:\
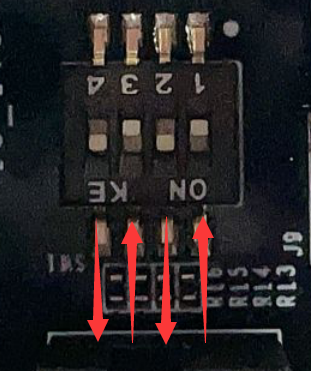
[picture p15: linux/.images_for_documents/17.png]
\
This position of the dial -dial switch is in the development board:\
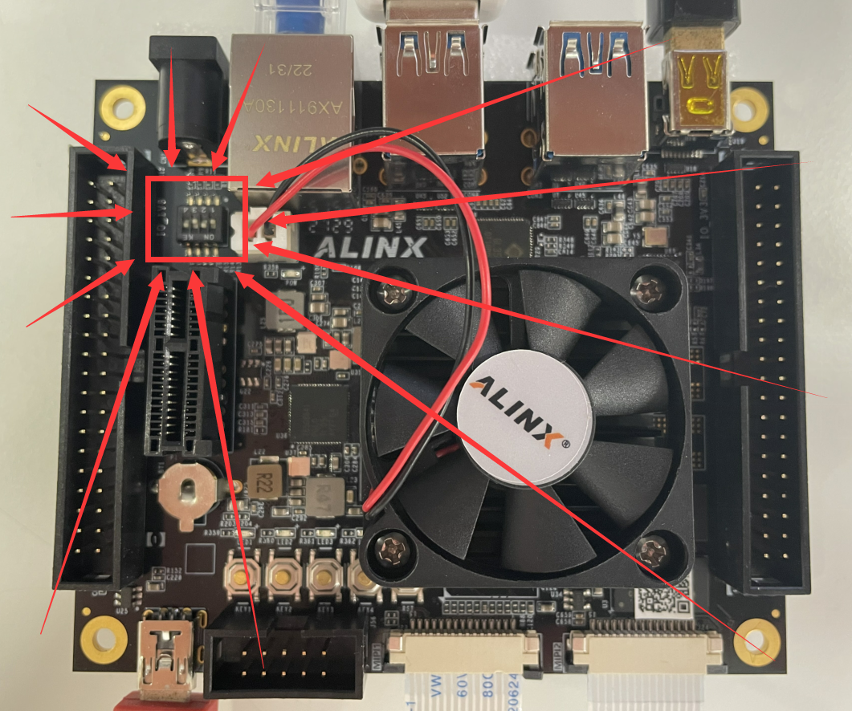
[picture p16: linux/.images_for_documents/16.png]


---
### 2.Set SD card partition
Next, you need to make the SD card for launching Linux. Connect the SD card (such as a card reader) to the Ubuntu system, and then open the DISKS tool in the Ubuntu system:\
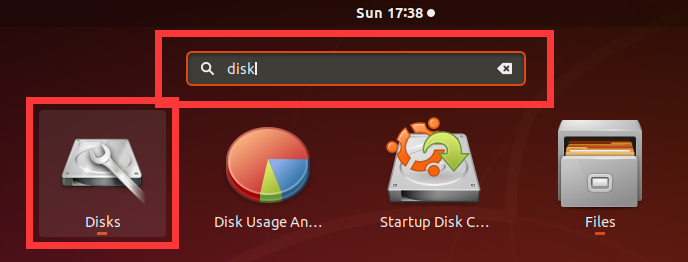
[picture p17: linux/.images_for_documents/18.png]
\
My SD card is the **31 GB Drive** here. Select it, you can see that there are three areas in the SD card:\
a. FAT type partition named **BOOT**\
b. Ext4 type partition named **ROOTFS**\
c. Free Space\
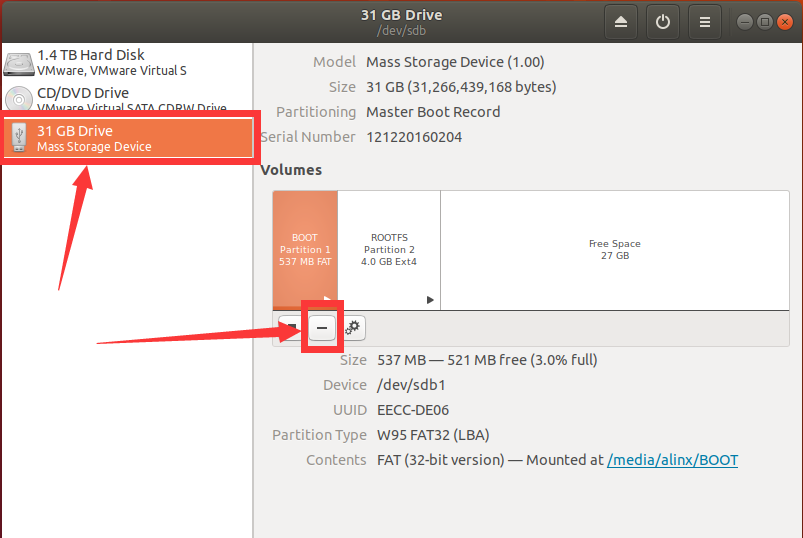
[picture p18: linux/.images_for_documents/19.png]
\
This is the state we need. If your SD card is in the same state (there is no strict requirement on the size of the partition), just skip step [2]. However, in order to demonstrate a complete process, I will restore the SD to the state without partition, select the corresponding partition, click the \" **-** \" icon to delete the current partition, and finally change to the state as shown below:\
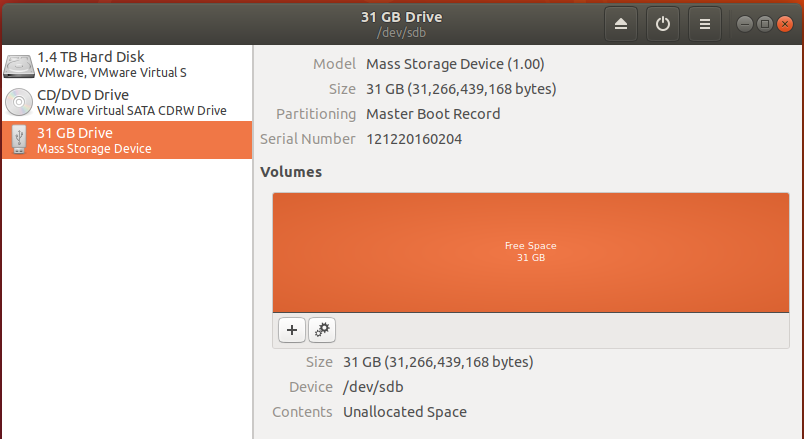
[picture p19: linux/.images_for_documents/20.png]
\
Click the \" **+** \" icon to create a new partition. The first partition needs to be in the format of **FAT**, with a size of 2G and a name of **BOOT**:\
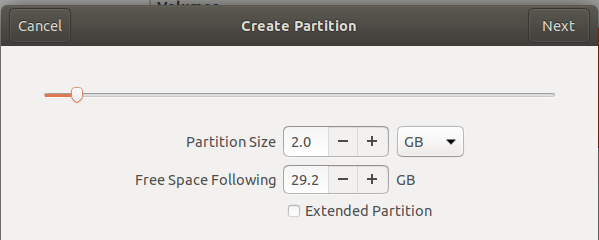
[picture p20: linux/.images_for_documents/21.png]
\
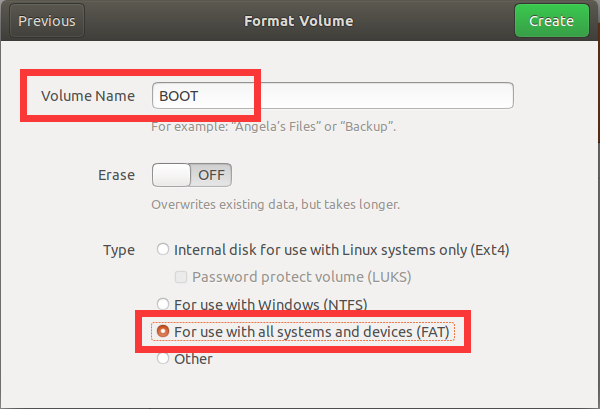
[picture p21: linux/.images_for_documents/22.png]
\
Click the **Create** button to complete the partition creation, and click \" **▶** \" button mount partition:\
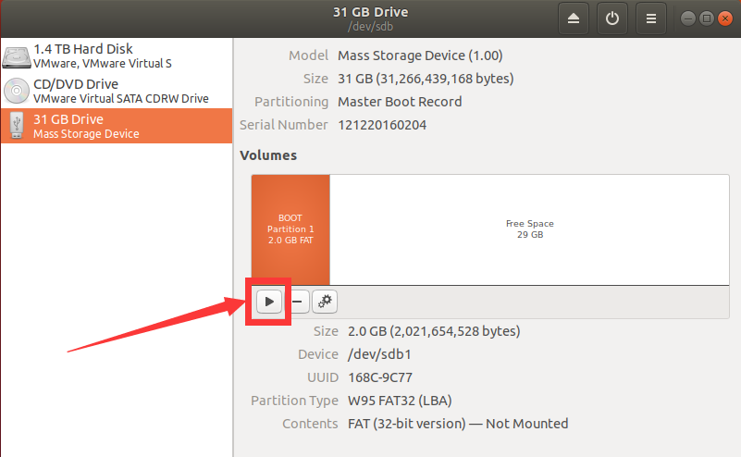
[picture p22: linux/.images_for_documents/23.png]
\
Click **Free Space** to create a second partition using similar steps. Select **Ext4** as the format. The size allocation is 20G (adjusted according to your actual needs and restrictions). The name is **ROOTFS**:\
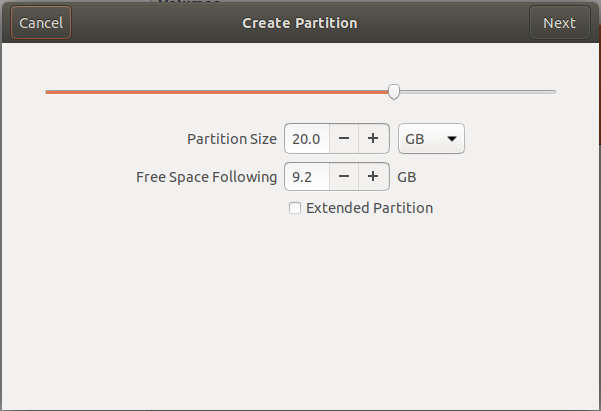
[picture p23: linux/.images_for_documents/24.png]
\
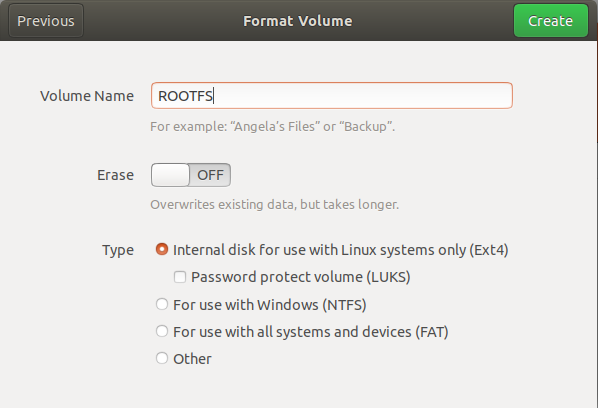
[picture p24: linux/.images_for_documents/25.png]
\
The final status is shown in the following figure. Note that you need to mount both partitions:\
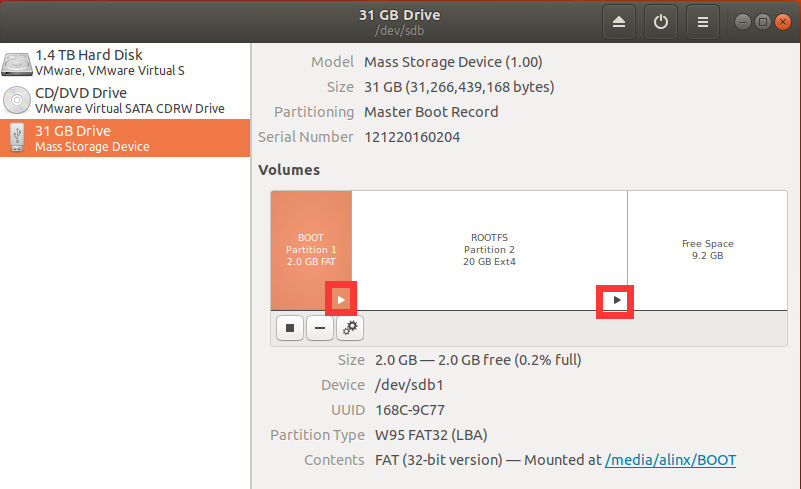
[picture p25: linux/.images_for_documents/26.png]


---
### 3.Populate SD card partitions
After the partition of the SD card is completed, copy the files needed to start the system to the corresponding partition.\
Ps: You can find *boot. scr*, *BOOT. bin*, *image. ub*, *rootfs. tar. gz*  in the release version. You can also compile the petalinux project to obtain these files.\
Copy the *boot.scr*, *BOOT.bin*, and *image.ub* files to the **BOOT** partition:\
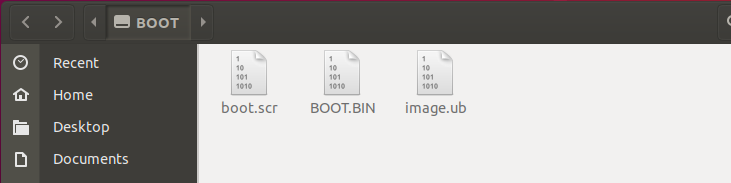
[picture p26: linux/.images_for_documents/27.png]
\
Extract *rootfs.tar.gz* to the **ROOTFS** partition with root privileges, open the terminal in the path of *rootfs.tar.gz*, and enter the following command:\
`sudo tar zxvf ./rootfs.tar.gz -C /media/alinx/ROOTFS/ && sync`\
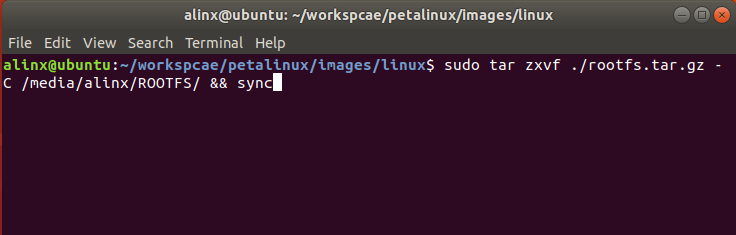
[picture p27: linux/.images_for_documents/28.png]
\
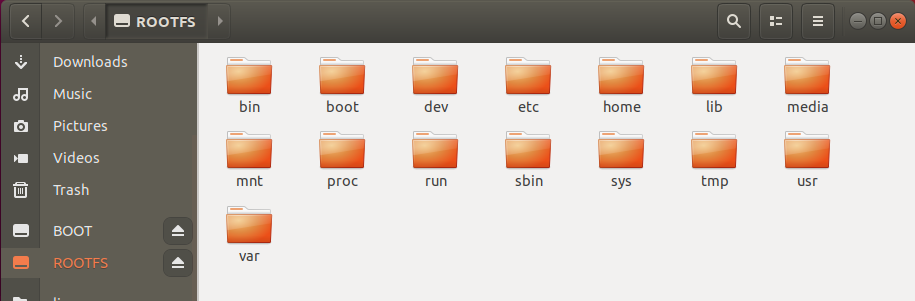
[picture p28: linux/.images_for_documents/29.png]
\
Then eject the SD card from Ubuntu.

---
### 4.Start Linux
Insert the SD card just made into the SD card slot of the development board:\
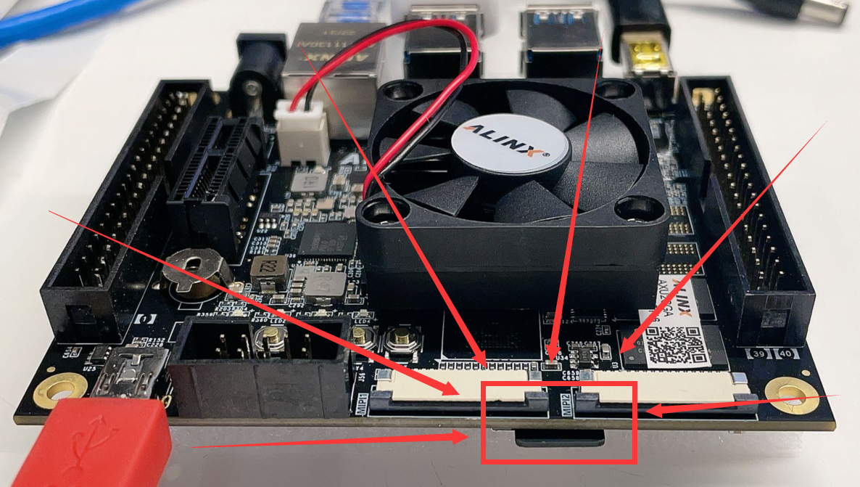
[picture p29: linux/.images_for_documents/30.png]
\
Connect PS_UART to PC (***The driver of CP210x needs to be installed on the PC*** ):\
\
Open the serial port tool, select the COM port we just connected, set the baud rate to 115200, close the flow control, and click the OK button:\
\
Connect 12V power supply:\
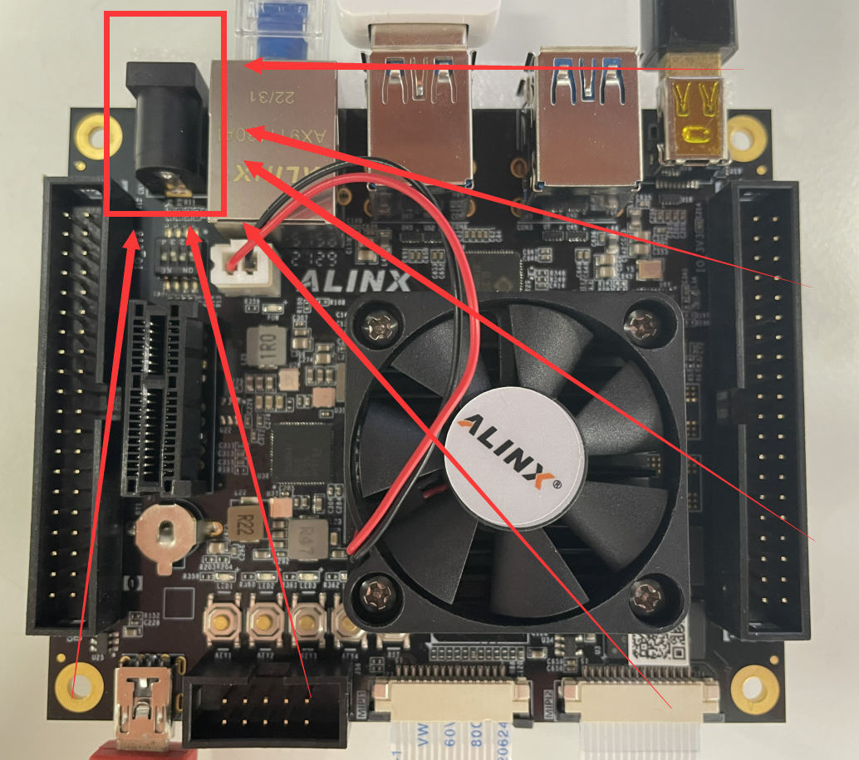
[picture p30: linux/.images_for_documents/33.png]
\
You can see the output information in the serial port tool:\
\
The system has been started successfully. Enter the user name **root** and password **root** to log in to the system.

---
---
- Visit [ALINX official website](https://www.alinx.com) for more information.

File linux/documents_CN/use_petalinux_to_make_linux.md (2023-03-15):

[返回首页](../)
## 创建和使用PETALINUX工程
- 关于XILINX开发套件的版本：**请务必使用2020.1版本的XILINX开发套件**，包括Vivado、Petalinux以及其他。
- 关于**离线编译**：petalinux工程编译时会从网上获取大量的必要资源，编译速度也依赖于网速，如果网络不稳定还有可能在等待很久之后编译失败，总之有很多弊端。因此**强烈建议使用离线编译**，首先从AMD|XILINX官网下载离线编译所需要的离线资源包[sstate_aarch64_2020.1.tar.gz](https://xilinx-ax-dl.entitlenow.com/dl/ul/2020/06/01/R210329478/sstate_aarch64_2020.1.tar.gz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)、[downloads_2020.1.tar.gz](https://xilinx-ax-dl.entitlenow.com/dl/ul/2020/06/01/R210329480/downloads_2020.1.tar.gz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)到Ubuntu系统的文件夹中并解压（解压完成后可以删除压缩包）。如下图：\
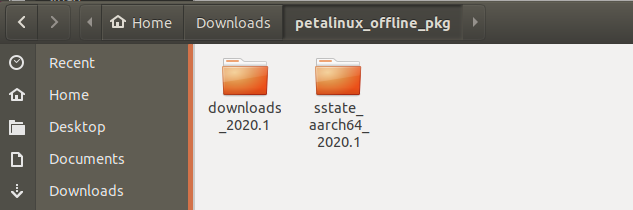
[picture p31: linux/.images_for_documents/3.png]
\
记录这两个包的路径，后面再介绍如何通过这两个路径来设置petalinux工程的离线编译。注意**加粗**的部分：\
/home/alinx/Downloads/petalinux_offline_pkg/sstate_aarch64_2020.1/**aarch64**
**file://**/home/alinx/Downloads/petalinux_offline_pkg/downloads_2020.1/**downloads**

---
### 方法一：使用本路径中的*PETALINUX工程文件夹*
1. 把本路径中的所有文件拷贝到Ubuntu系统的文件夹中，如下图：\
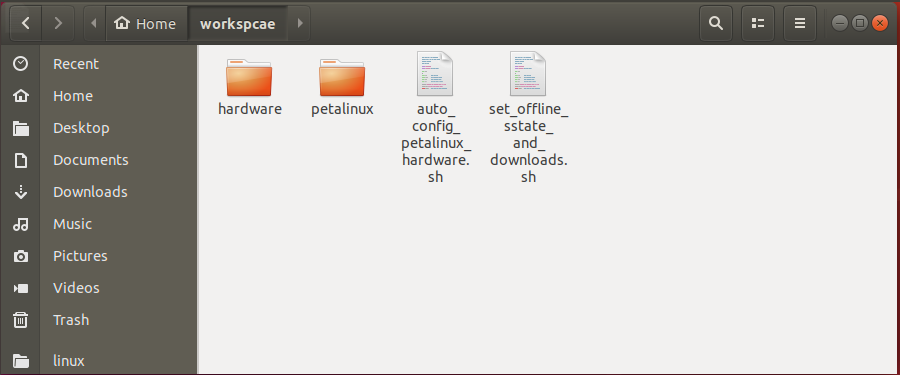
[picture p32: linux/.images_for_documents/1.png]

2. 在这个路径中打开终端，设置petalinux的环境变量。\
如果你的petalinux工具和我一样安装在 */opt/pkg/petalinux* 路径，则使用下面命令来设置环境变量：\
`source /opt/pkg/petalinux/settings.sh`\
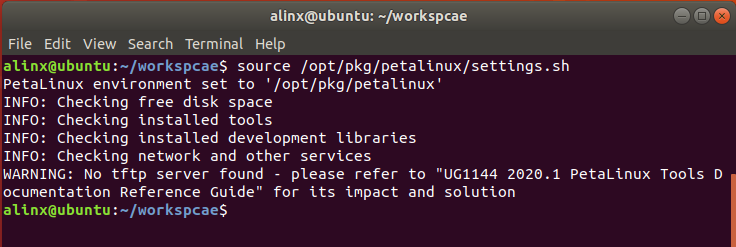
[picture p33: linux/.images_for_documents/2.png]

3. 使用*hardware* 路径中的硬件描述文件来配置petalinux工程的硬件信息，可以使用*auto_config_petalinux_hardware.sh* 脚本来完成设置，如下图：\
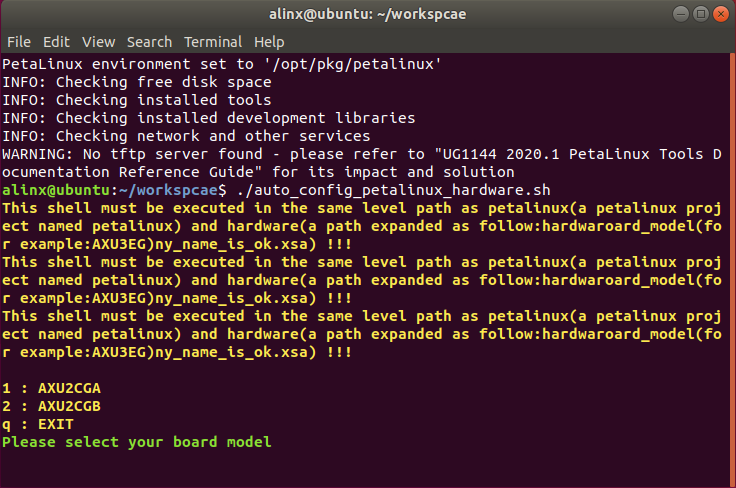
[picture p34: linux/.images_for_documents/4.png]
\
根据提示完成操作，选择你的开发板型号，我以AXU2CG为例：\
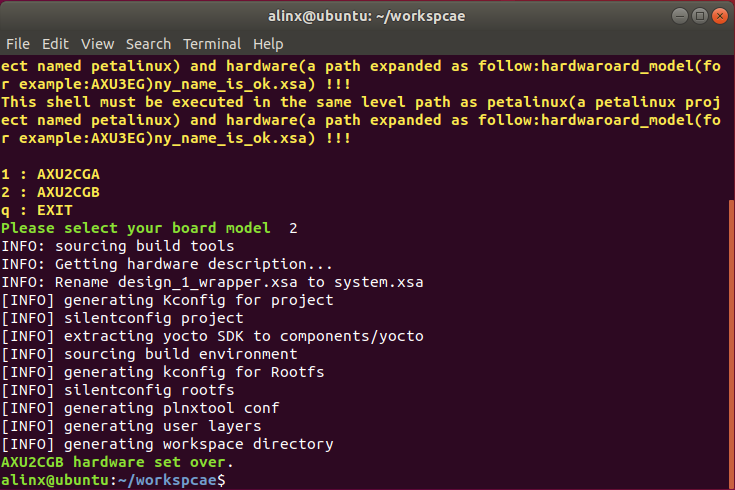
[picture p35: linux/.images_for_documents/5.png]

4. 如果你不需要或者不想使用离线编译，则可以跳过这一步。使用*set_offline_sstate_and_downloads.sh* 脚本设置离线编译：\
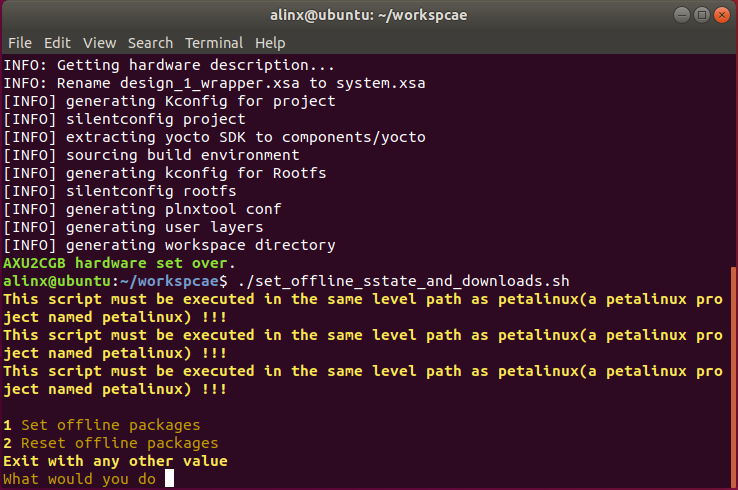
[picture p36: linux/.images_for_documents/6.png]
\
输入1设置离线编译，输入2恢复成在线编译，输入其他任意值退出脚本，这里我选择1。因为我的sstate资源包路径和默认的设置相同，所以直接按回车就可以了。如果你的sstate资源包路径和默认的路径不同，则需要在这里输入你的路径然后按回车：\
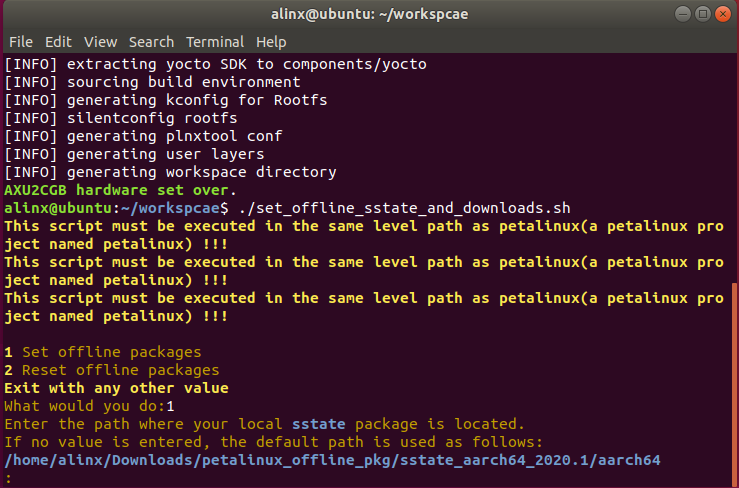
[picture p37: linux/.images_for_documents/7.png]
\
然后downloads资源包路径也是一样的设置。按回车等待提示*offline package set over*：\
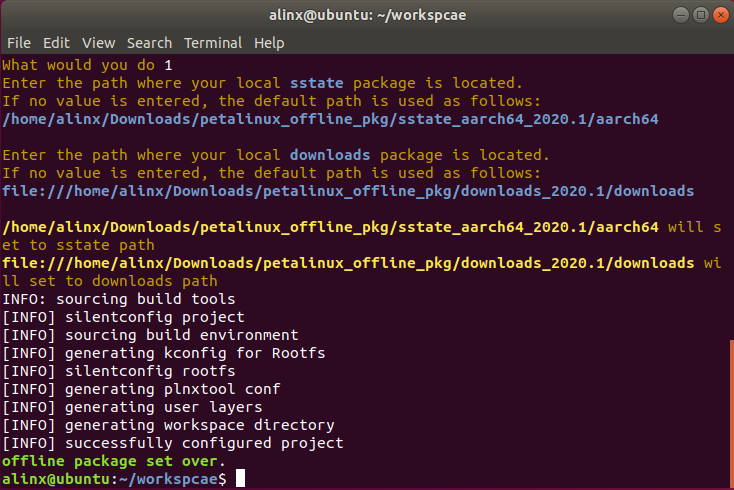
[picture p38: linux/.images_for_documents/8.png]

5. 现在就可以编译petalinux工程了，在终端中输入下面的命令编译工程并在编译完成后打包BOOT.bin：\
`cd ./petalinux && petalinux-build && petalinux-package --boot --u-boot --fsbl --fpga --force`\
即使是使用离线编译，每个工程的第一次编译都会花上较长的时间。耐心等待编译完成：\
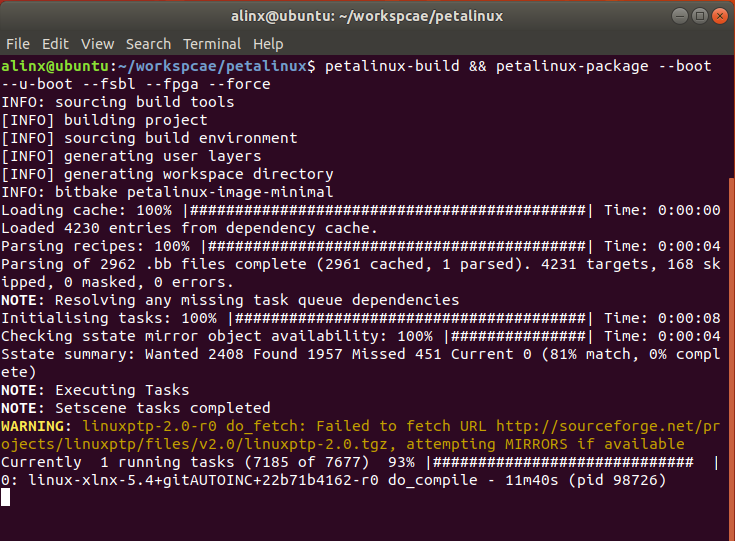
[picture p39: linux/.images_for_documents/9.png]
\
编译成功!!!并且打包了BOOT.bin：\
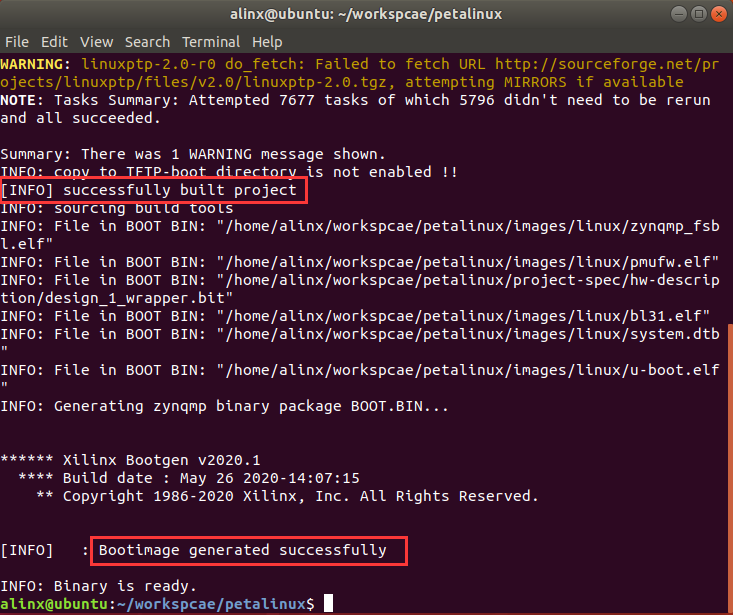
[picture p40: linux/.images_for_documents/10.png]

6. 查看petalinux工程 */image/linux* 路径，这里就是编译和打包的结果文件。我们需要其中的BOOT.bin、image.ub、boot.scr以及rootfs.tar.gz这四个文件，在开发板上启动LINUX：\
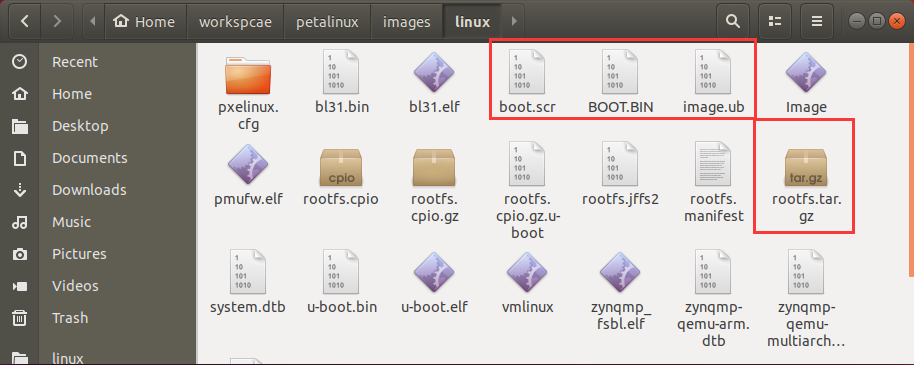
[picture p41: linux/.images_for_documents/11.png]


---
### 方法二：使用RELEASE版本中的BSP包创建PETALINUX工程
1. 把bsp文件拷贝到Ubuntu系统的文件夹中，以AXU4EV-E为例，如下图：\
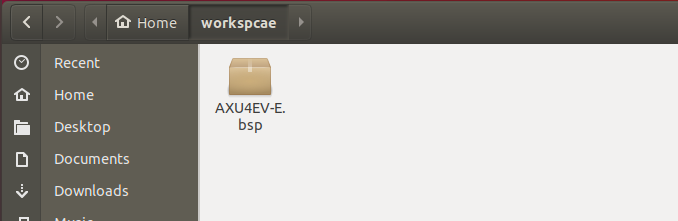
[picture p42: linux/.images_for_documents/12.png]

2. 在当前路径中打开终端，设置petalinux的环境变量。\
如果你的petalinux工具和我一样安装在 /opt/pkg/petalinux 路径，则使用下面命令来设置环境变量：\
`source /opt/pkg/petalinux/settings.sh`
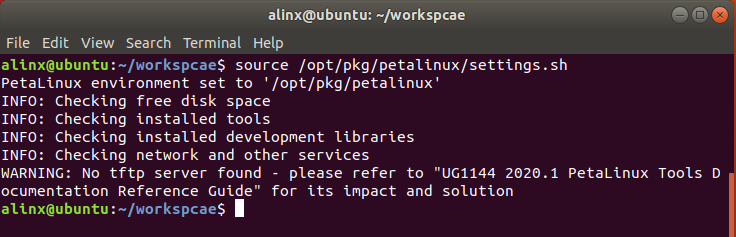
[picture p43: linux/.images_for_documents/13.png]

3. 用下面的命令，通过petalinux的bsp包来创建petalinux工程：\
`petalinux-create -t project -n petalinux -s ./AXU4EV-E.bsp`\
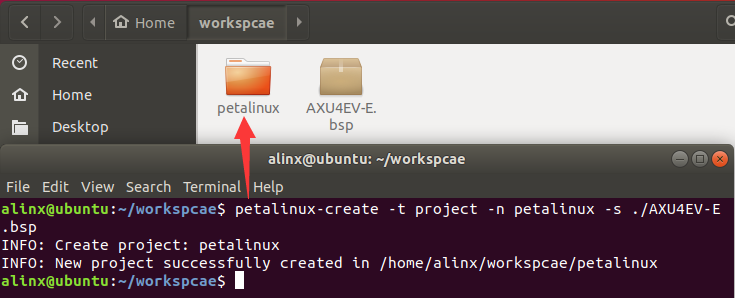
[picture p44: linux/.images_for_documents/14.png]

4. 如果需要配置离线编译，参考**方法一**的步骤 **[4]**。
5. 使用bsp包创建的petalinux工程不需任何设置，进入petalinux工程路径\
`cd ./petalinux/`\
直接编译并打包BOOT.bin即可：\
`petalinux-build && petalinux-package --boot --u-boot --fsbl --fpga --force`\
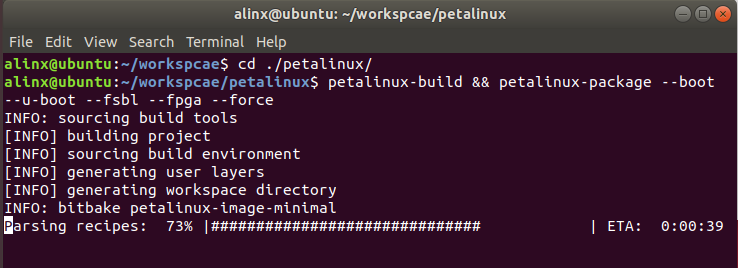
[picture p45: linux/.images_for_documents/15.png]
\
编译和打包完成后，结果文件在petalinux工程的 */image/linux* 路径中：\


---
---
- 访问[ALINX官方网站](https://www.alinx.com)以获取更多信息。

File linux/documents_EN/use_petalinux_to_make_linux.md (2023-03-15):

[Back to Home](../)
## Create and use PETALINUX project
- About the version of XILINX development kit: **Please be sure to use the 2020.1 version of XILINX development kit**, including Vivado, Petalinux and others.
- About the **offline compilation**: Petalinux project will obtain a lot of necessary resources from the Internet when compiling, and the speed of compilation depends on the network speed. If the network is unstable, it may have failed to compile after a long wait. In short, there are many disadvantages. Therefore, **it is strongly recommended to use offline compilation**. First, download the offline resource packages\([sstate_aarch64_2020.1.tar.gz](https://xilinx-ax-dl.entitlenow.com/dl/ul/2020/06/01/R210329478/sstate_aarch64_2020.1.tar.gz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)、[downloads_2020.1.tar.gz](https://xilinx-ax-dl.entitlenow.com/dl/ul/2020/06/01/R210329480/downloads_2020.1.tar.gz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)\) required for offline compilation from AMD|XILINX official website to the folder of the Ubuntu system and decompress (you can delete the compressed package after decompression). As shown below :\
\
Record the paths of these two packages. Later, we will introduce how to set the offline compilation of the petalinux project through these two paths. Note **Bold** :\
/home/alinx/Downloads/petalinux_offline_pkg/sstate_aarch64_2020.1/**aarch64**\
**file://**/home/alinx/Downloads/petalinux_offline_pkg/downloads_2020.1/**downloads**

---
### Method 1: Use the *PETALINUX project folder* in this path
1. Copy all files in this path to the Ubuntu system folder, as shown below :\

2. Open the terminal in this path and set the environment variable of petalinux.\
If your petalinux tool is installed in the */opt/pkg/petalinux* path like me, use the following command to set the environment variables :\
`source /opt/pkg/petalinux/settings.sh`\

3. Use the hardware description file in the*Hardware*path to configure the hardware information of the petalinux project. You can use*Auto_config_petalinux_hardware.sh* to complete the settings, as shown below :\
\
After completing the operation according to the prompt, select your development board model, here I use AXU2CGB as an example :\

4. If you do not need or want to use offline compilation, you can skip this step. Use *set_offline_sstate_and_Downloads.sh* script to set offline compilation :\
\
Enter **1** to set offline compilation, enter **2** to restore petalinux project into online compilation, and enter other arbitrary values to exit the script. Here I choose 1. My SSTATE resource package path is the same as the default settings, so I just press Enter directly. If your SSTATE resource package path is different from the default path, you need to enter your path here and then press Enter : \
\
Then DOWNLOADS resource package path is the same. Press Enter and wait for the prompt *Offline package set over* :\

5. Now you can compile the Petalinux project. Enter the following command in the terminal to compile the project and package BOOT.bin after the compilation is completed :\
`cd ./petalinux && petalinux-build && petalinux-package --boot --u-boot --fsbl --fpga --force`\
Even if it is compiled offline, the first compilation of each project will take a longer time. Please wait patiently for the compilation to complete :\
\
Compilation succeeded!!! And the BOOT.bin is packaged :\
 
6. Check the */image/linux* path in the petalinux project. Here is the compiled and packaged result file. We need *BOOT.bin*, *image.ub*, *boot.scr* and *rootfs.tar.gz* to start LINUX on the development board:\


---
### Method 2: Use the BSP package in the RELEASE version to create a petalinux project
1. Copy the bsp file to the Ubuntu system folder, taking AXU4EV-E as an example, as shown in the following figure :\

2. Open the terminal in this path and set the environment variable of petalinux.\
If your petalinux tool is installed in the */opt/pkg/petalinux* path like me, use the following command to set the environment variables :\
`source /opt/pkg/petalinux/settings.sh`

3. Use the following command to create a petalinux project through the bsp package of petalinux :\
`petalinux-create -t project -n petalinux -s ./AXU4EV-E.bsp`\

4. If you need to configure offline compilation, refer to step **[4]** of **Method 1**.
5. The petalinux project created by using the bsp package does not need any settings. Enter the petalinux project path :\
`cd ./petalinux/`\
Directly compile and package BOOT.bin :\
`petalinux-build && petalinux-package --boot --u-boot --fsbl --fpga --force`\
\
After compilation and packaging, the result file is in the */image/linux* path of the petalinux project :\


---
---
- Visit [ALINX official website](https://www.alinx.com) for more information.

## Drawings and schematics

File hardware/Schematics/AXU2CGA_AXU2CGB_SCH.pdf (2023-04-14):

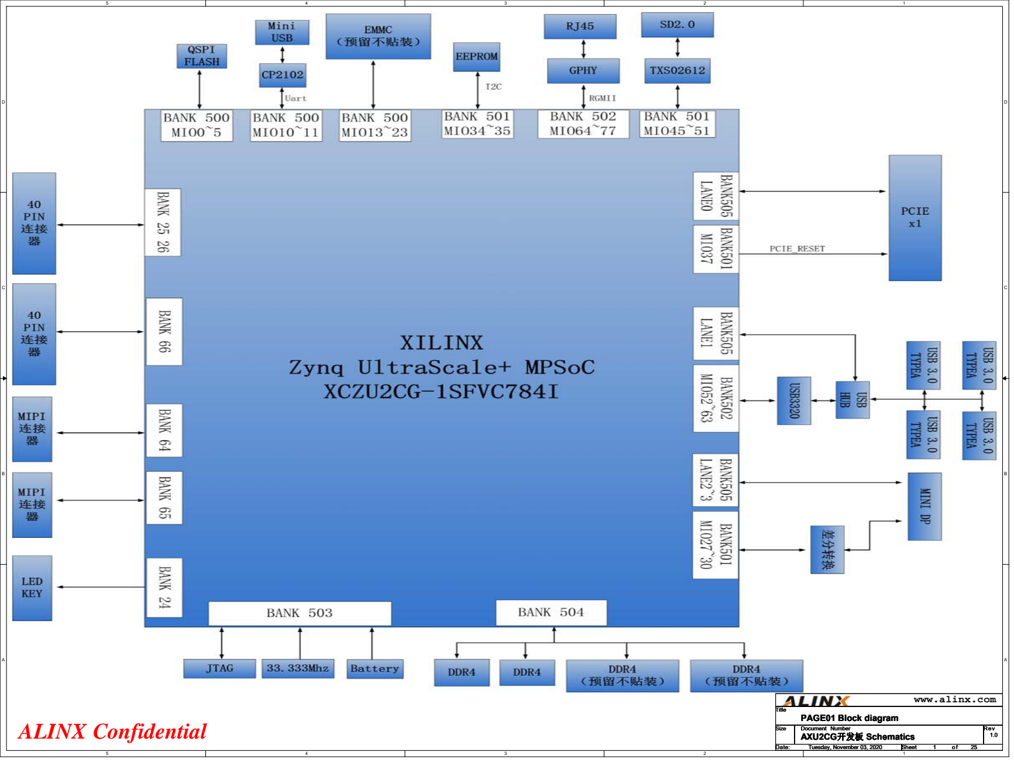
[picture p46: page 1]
ALINX Confidential; Title; PAGE01 Block diagram

www.alinx.com

Size | Document Number AXU2CG开发板 Schematics | Rev 1.0

Date: Tuesday, November 03, 2020 Tuesday, November 03, 2020 Tuesday, November 03, 2020 | Sheet 1 1 1 of 25 25 25

# MODE[3:0]

0000 | PS JTAG | PS JTAG Interface

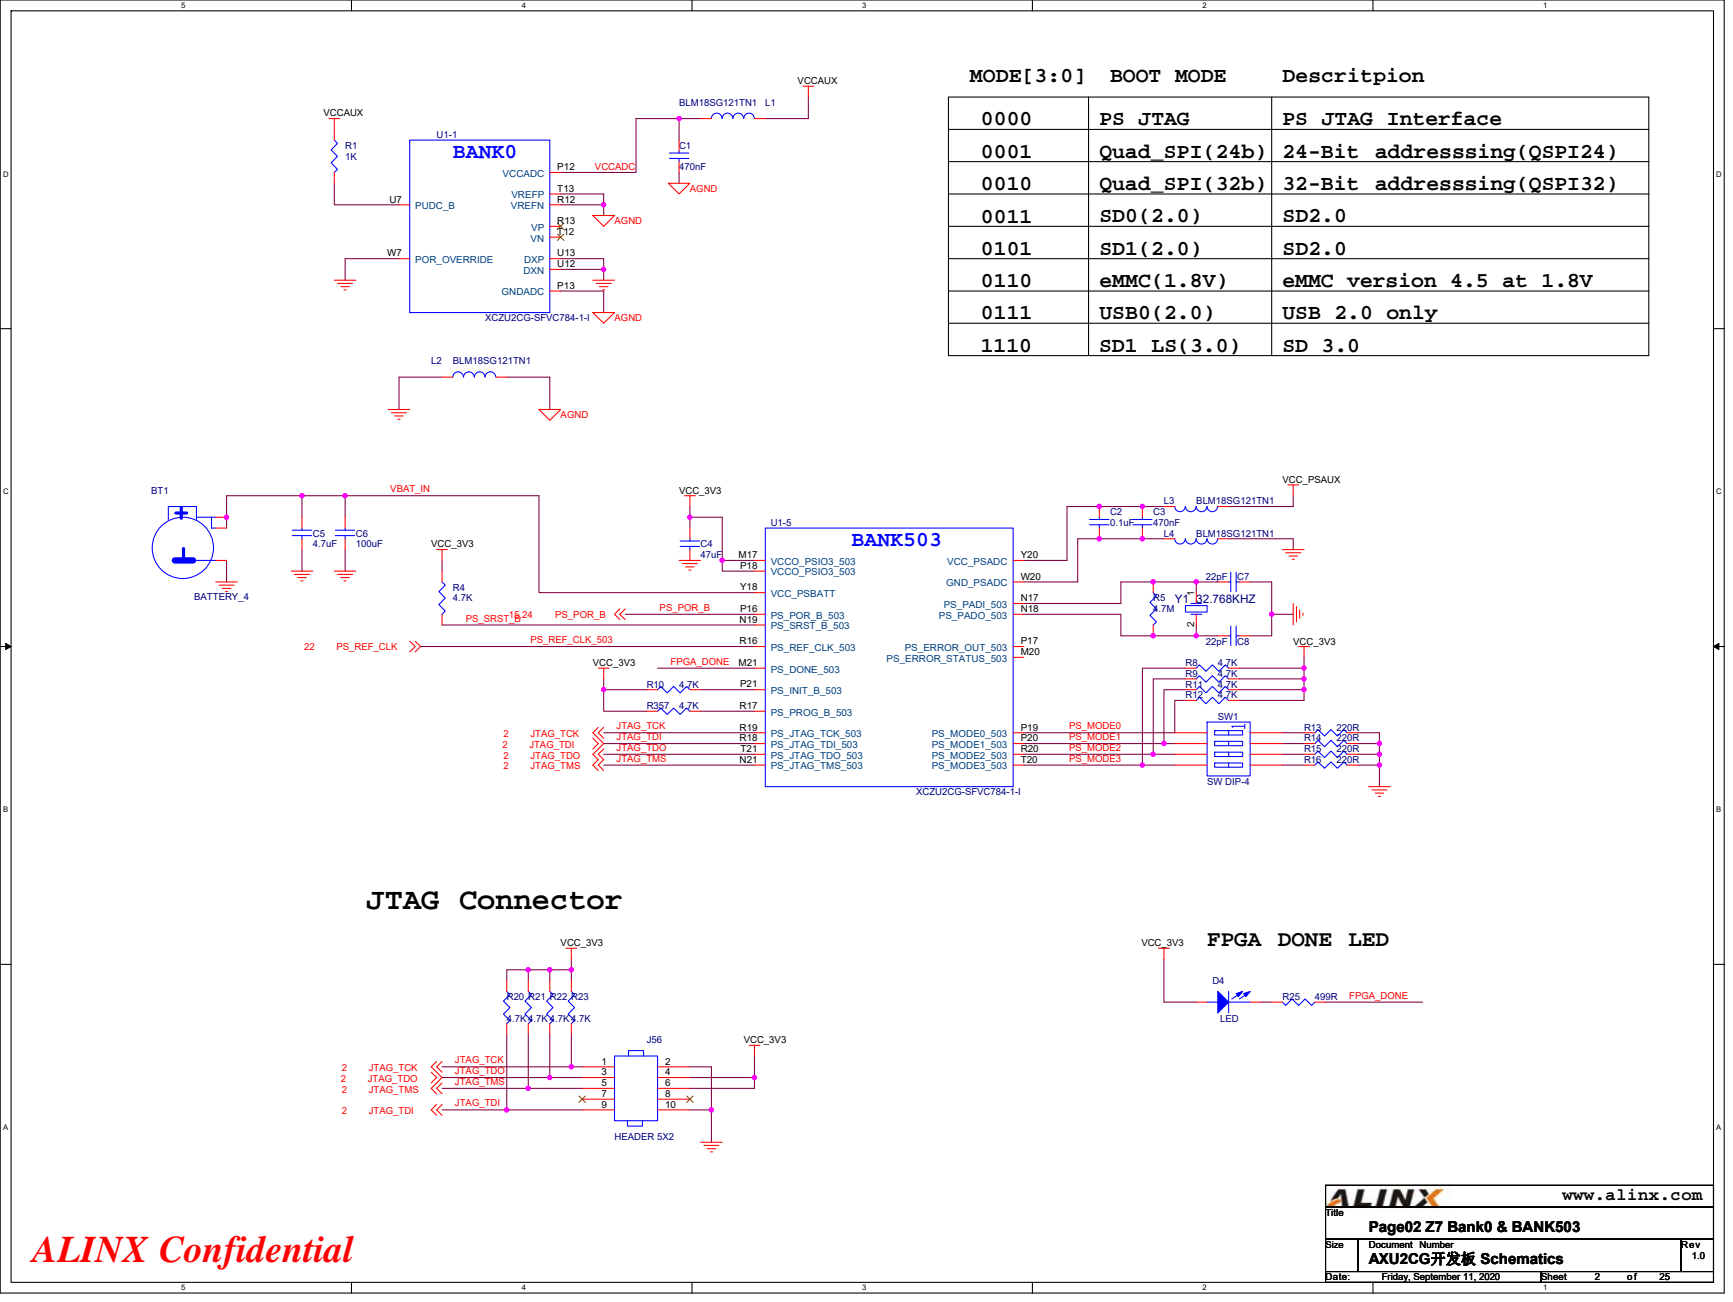
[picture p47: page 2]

0001 | Quad_SPI(24b) | 24-Bit addresssing(QSPI24)
0010 | Quad_SPI(32b) | 32-Bit addresssing(QSPI32)
0011 | SD0(2.0) | SD2.0
0101 | SD1(2.0) | SD2.0
0110 | eMMC(1.8V) | eMMC version 4.5 at 1.8V

## VCC1V8

SD0

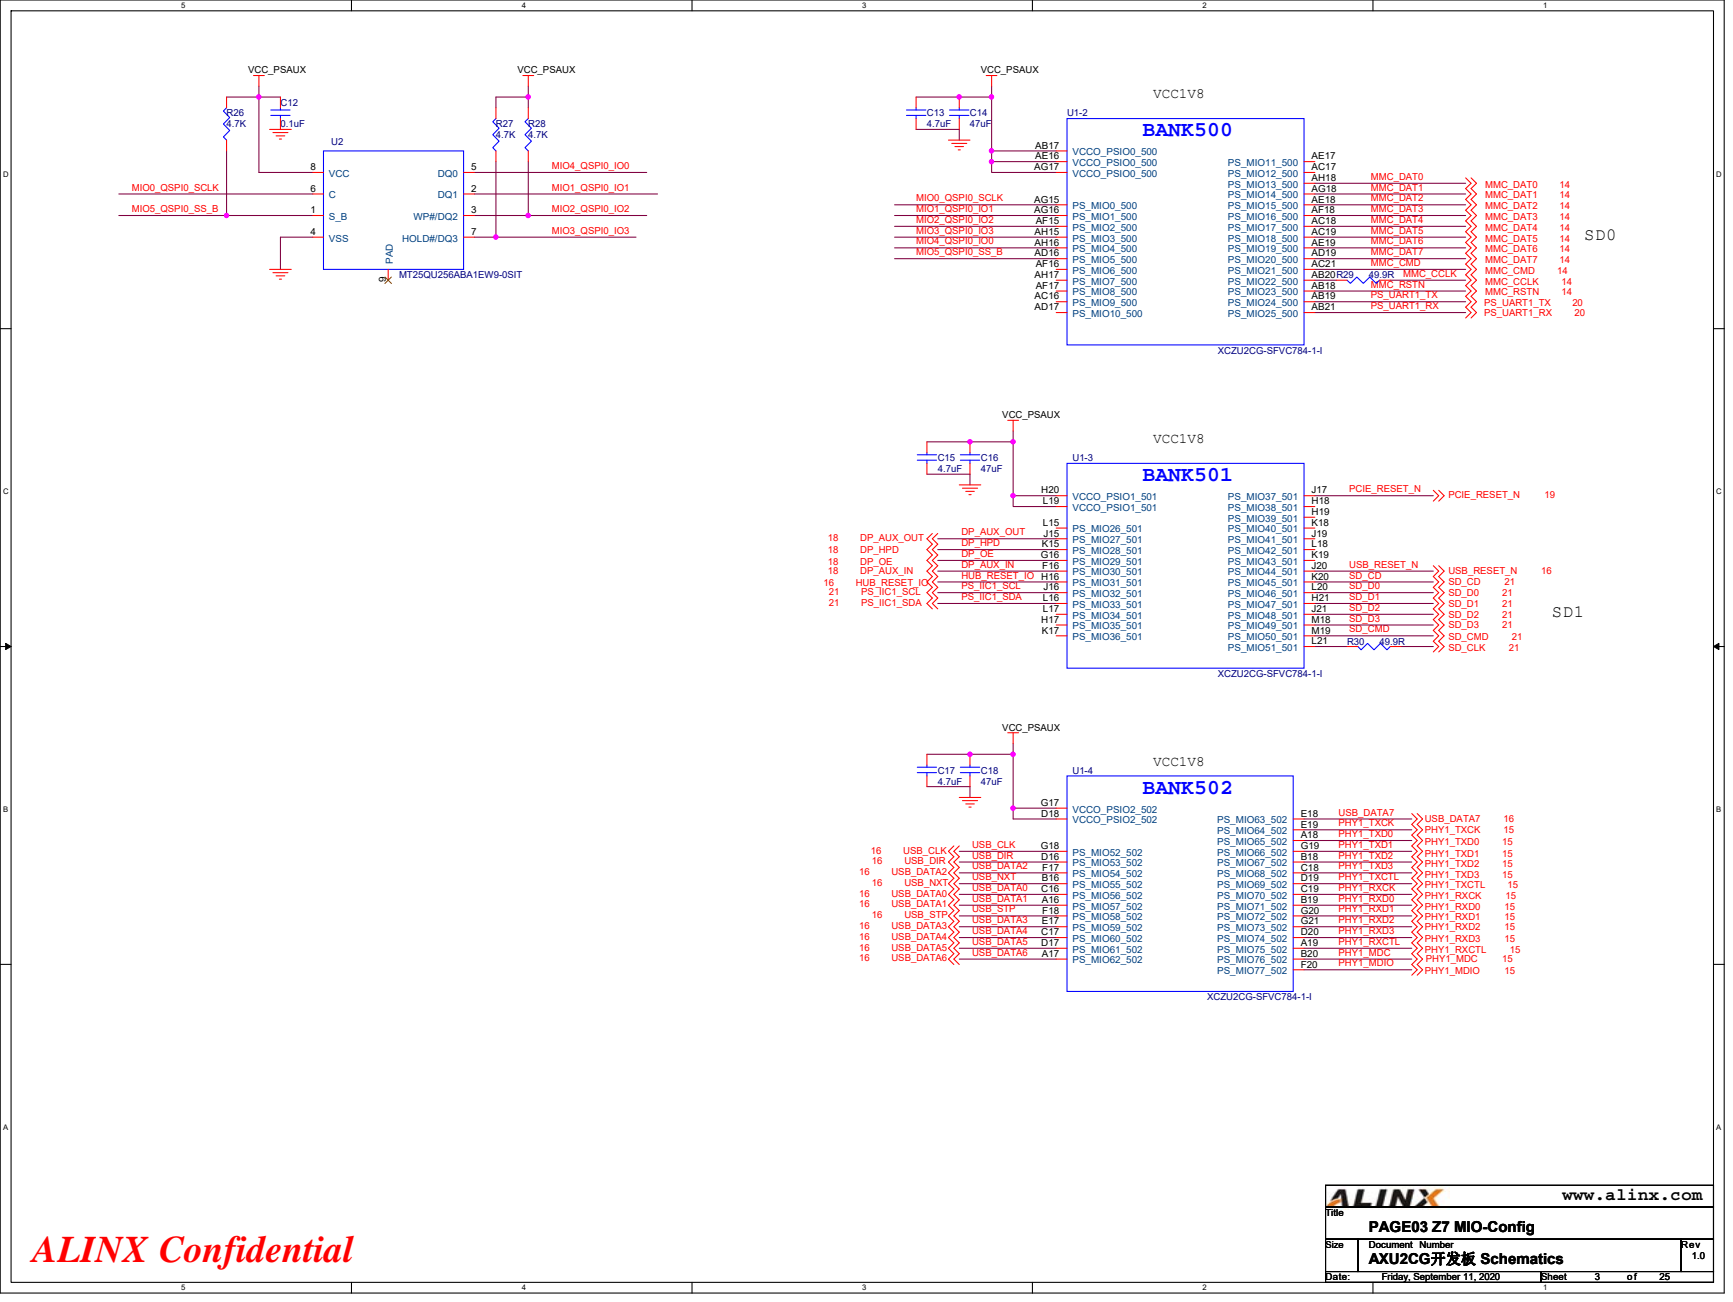
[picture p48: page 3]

47uF | BANK44

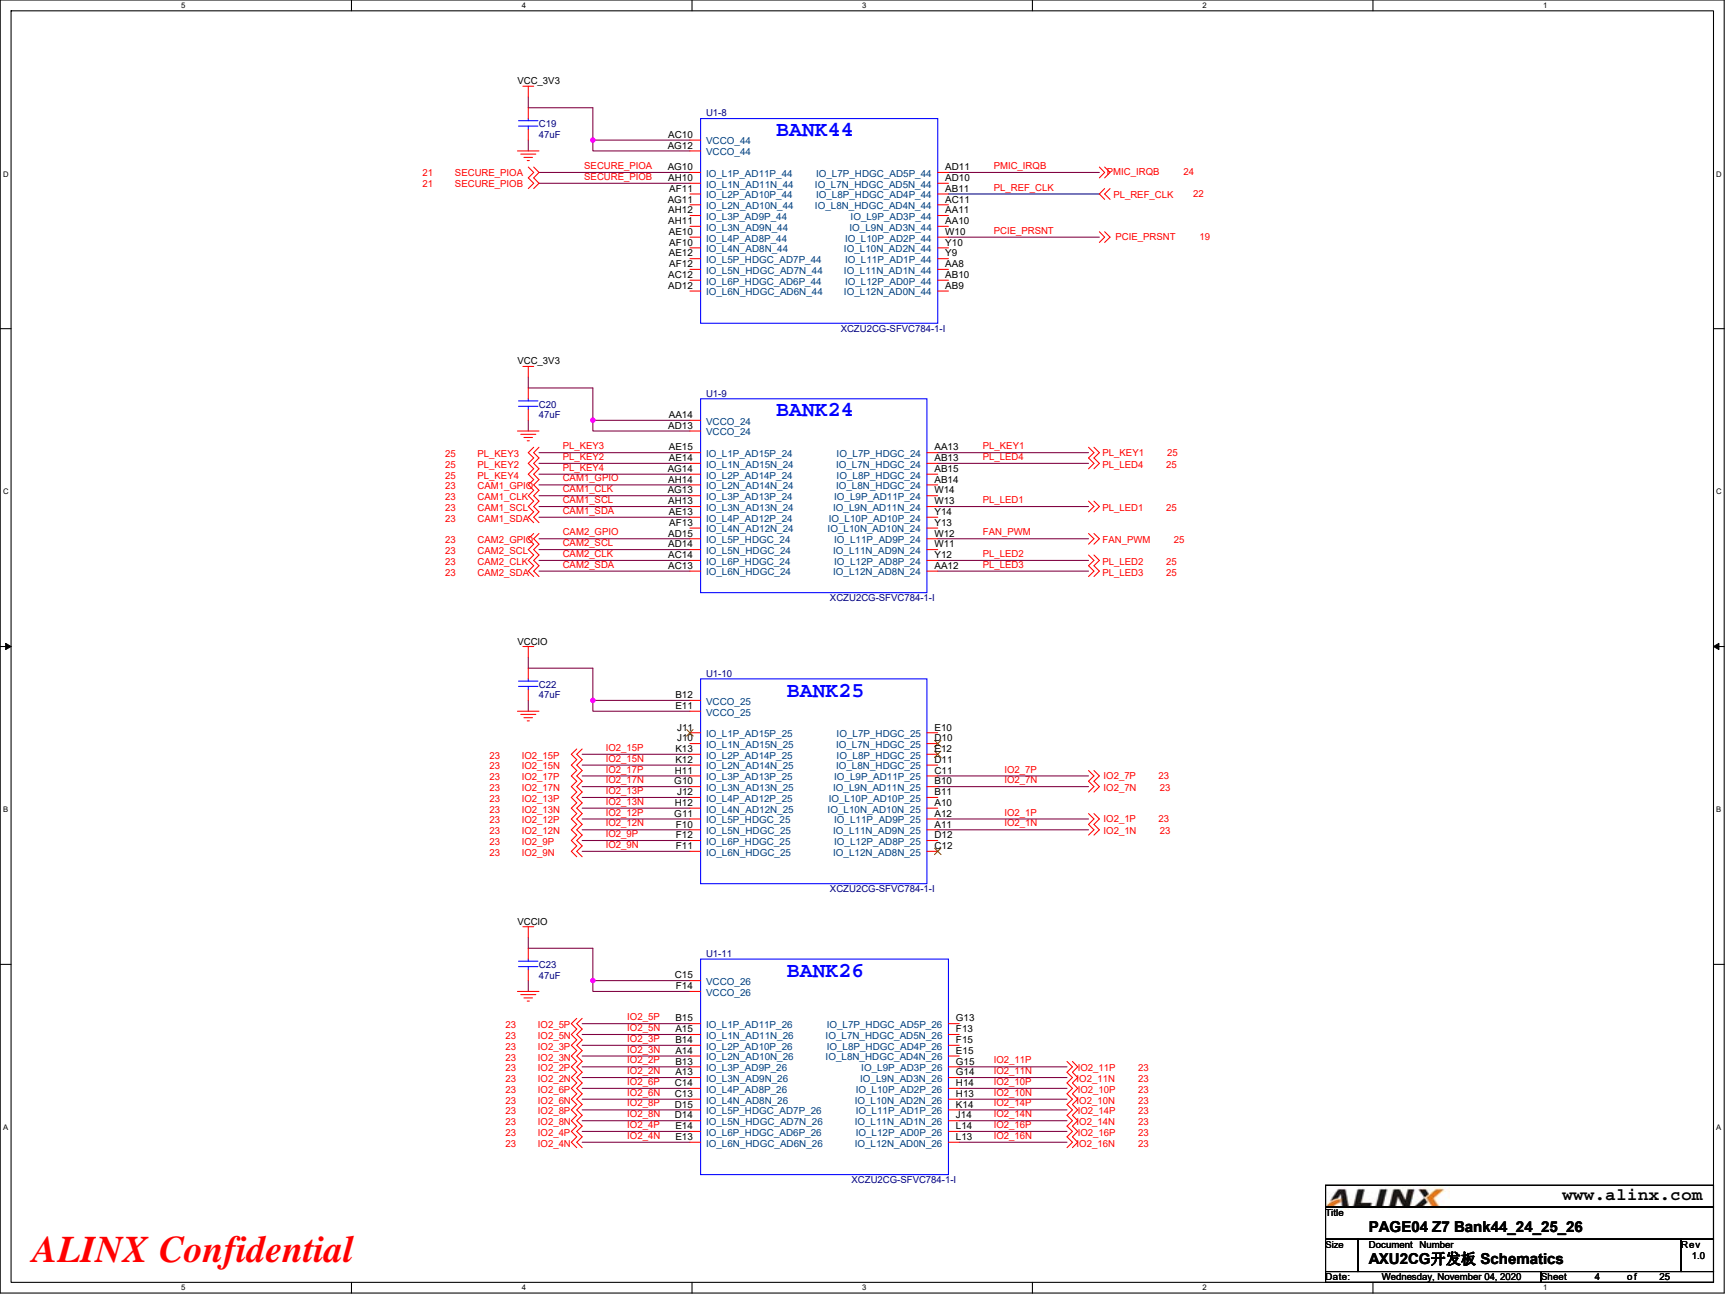
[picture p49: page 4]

+1.2V

# BANK64

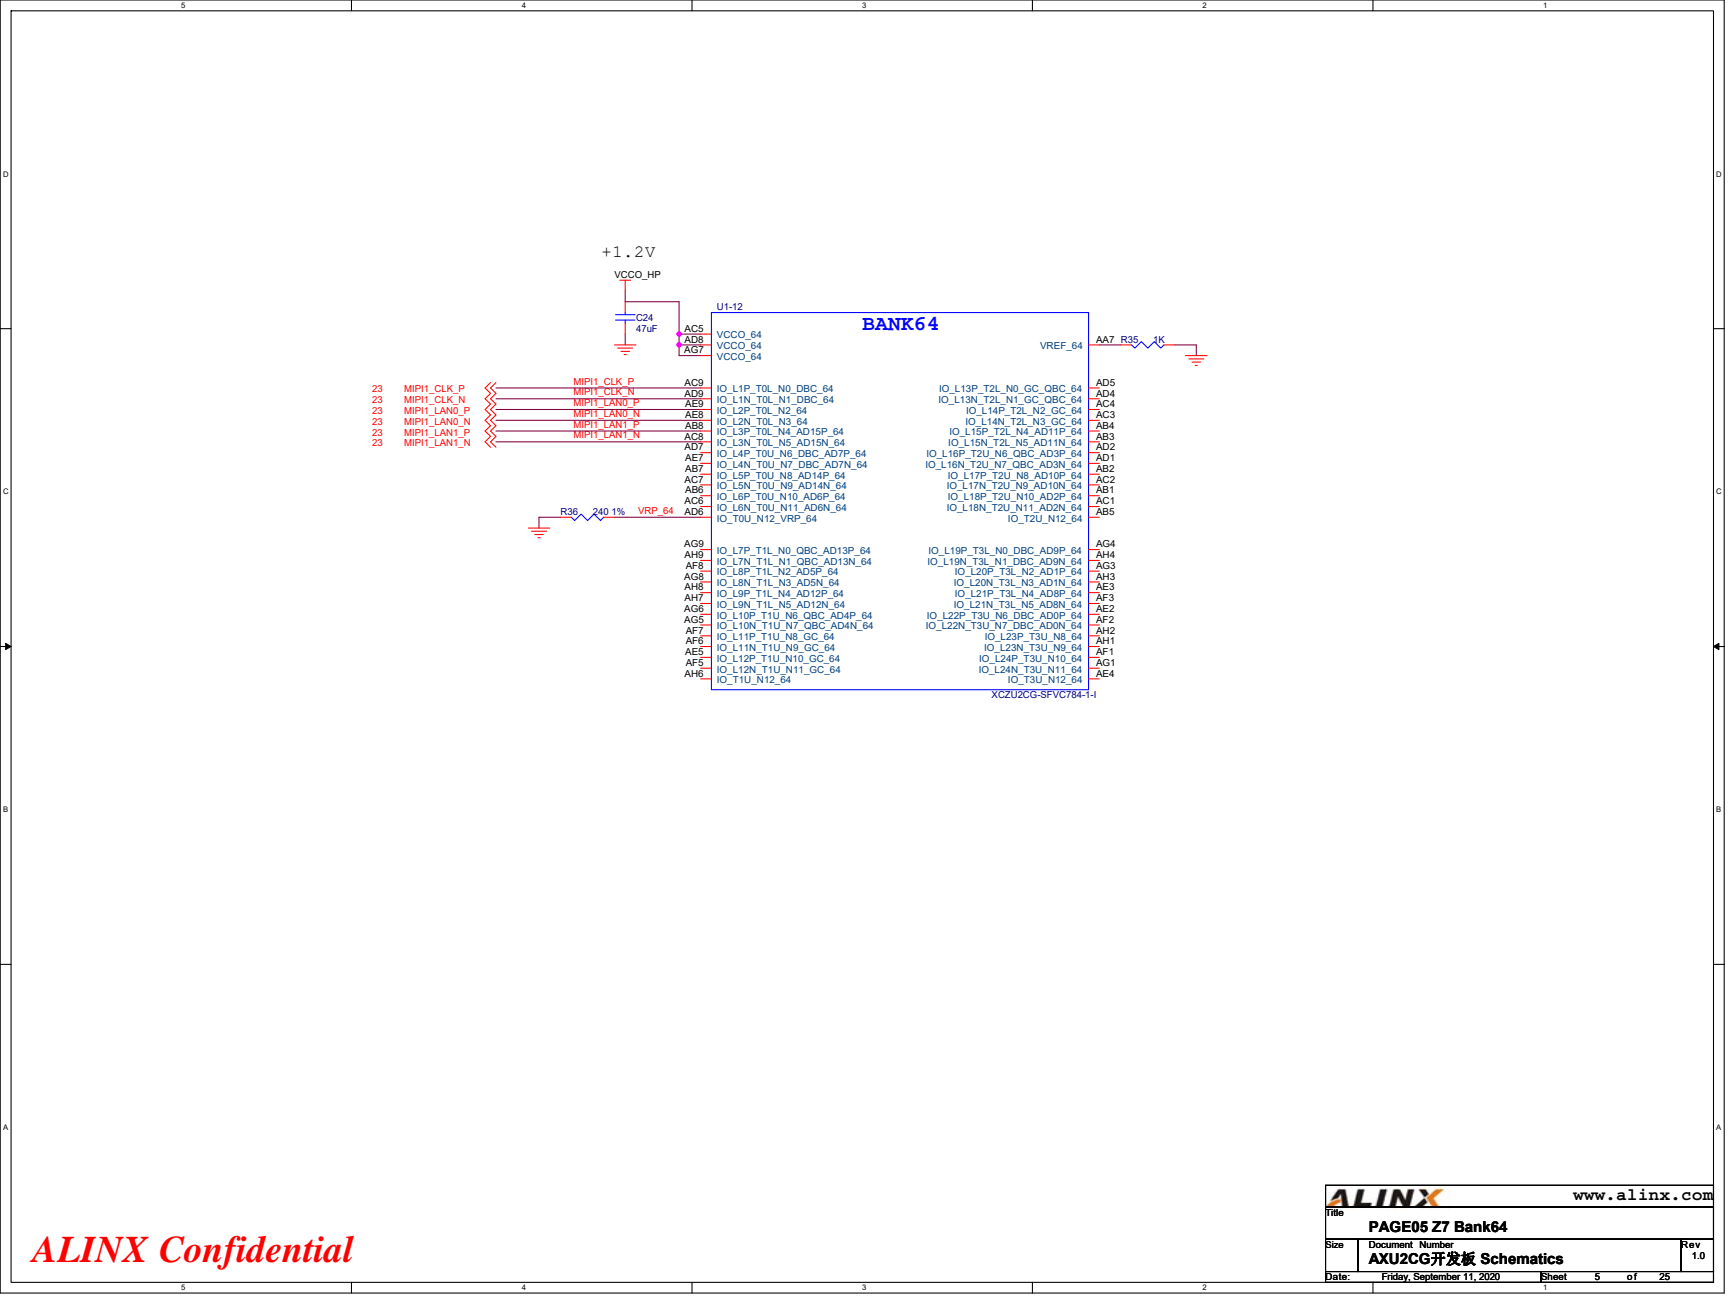
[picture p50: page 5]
VRP_64; MIPI1_CLK_N; MIPI1_CLK_P; MIPI1_LAN0_N; MIPI1_LAN0_P; MIPI1_LAN1_N; MIPI1_LAN1_P; VCCO_HP; PAGE05 Z7 Bank64; Friday, September 11, 2020; XCZU2CG-SFVC784-1-I; IO_T0U_N12_VRP_64 AD6; IO_L1N_T0L_N1_DBC_64 AD9; IO_L1P_T0L_N0_DBC_64 AC9; IO_L4N_T0U_N7_DBC_AD7N_64 AE7; IO_L4P_T0U_N6_DBC_AD7P_64 AD7; IO_L7N_T1L_N1_QBC_AD13N_64 AH9; IO_L7P_T1L_N0_QBC_AD13P_64 AG9; IO_L10N_T1U_N7_QBC_AD4N_64 AG5; IO_L10P_T1U_N6_QBC_AD4P_64 AG6; VCCO_64 AC5 VCCO_64 AD8 VCCO_64 AG7; IO_L13N_T2L_N1_GC_QBC_64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

www.alinx.com

+1.2V

# BANK65

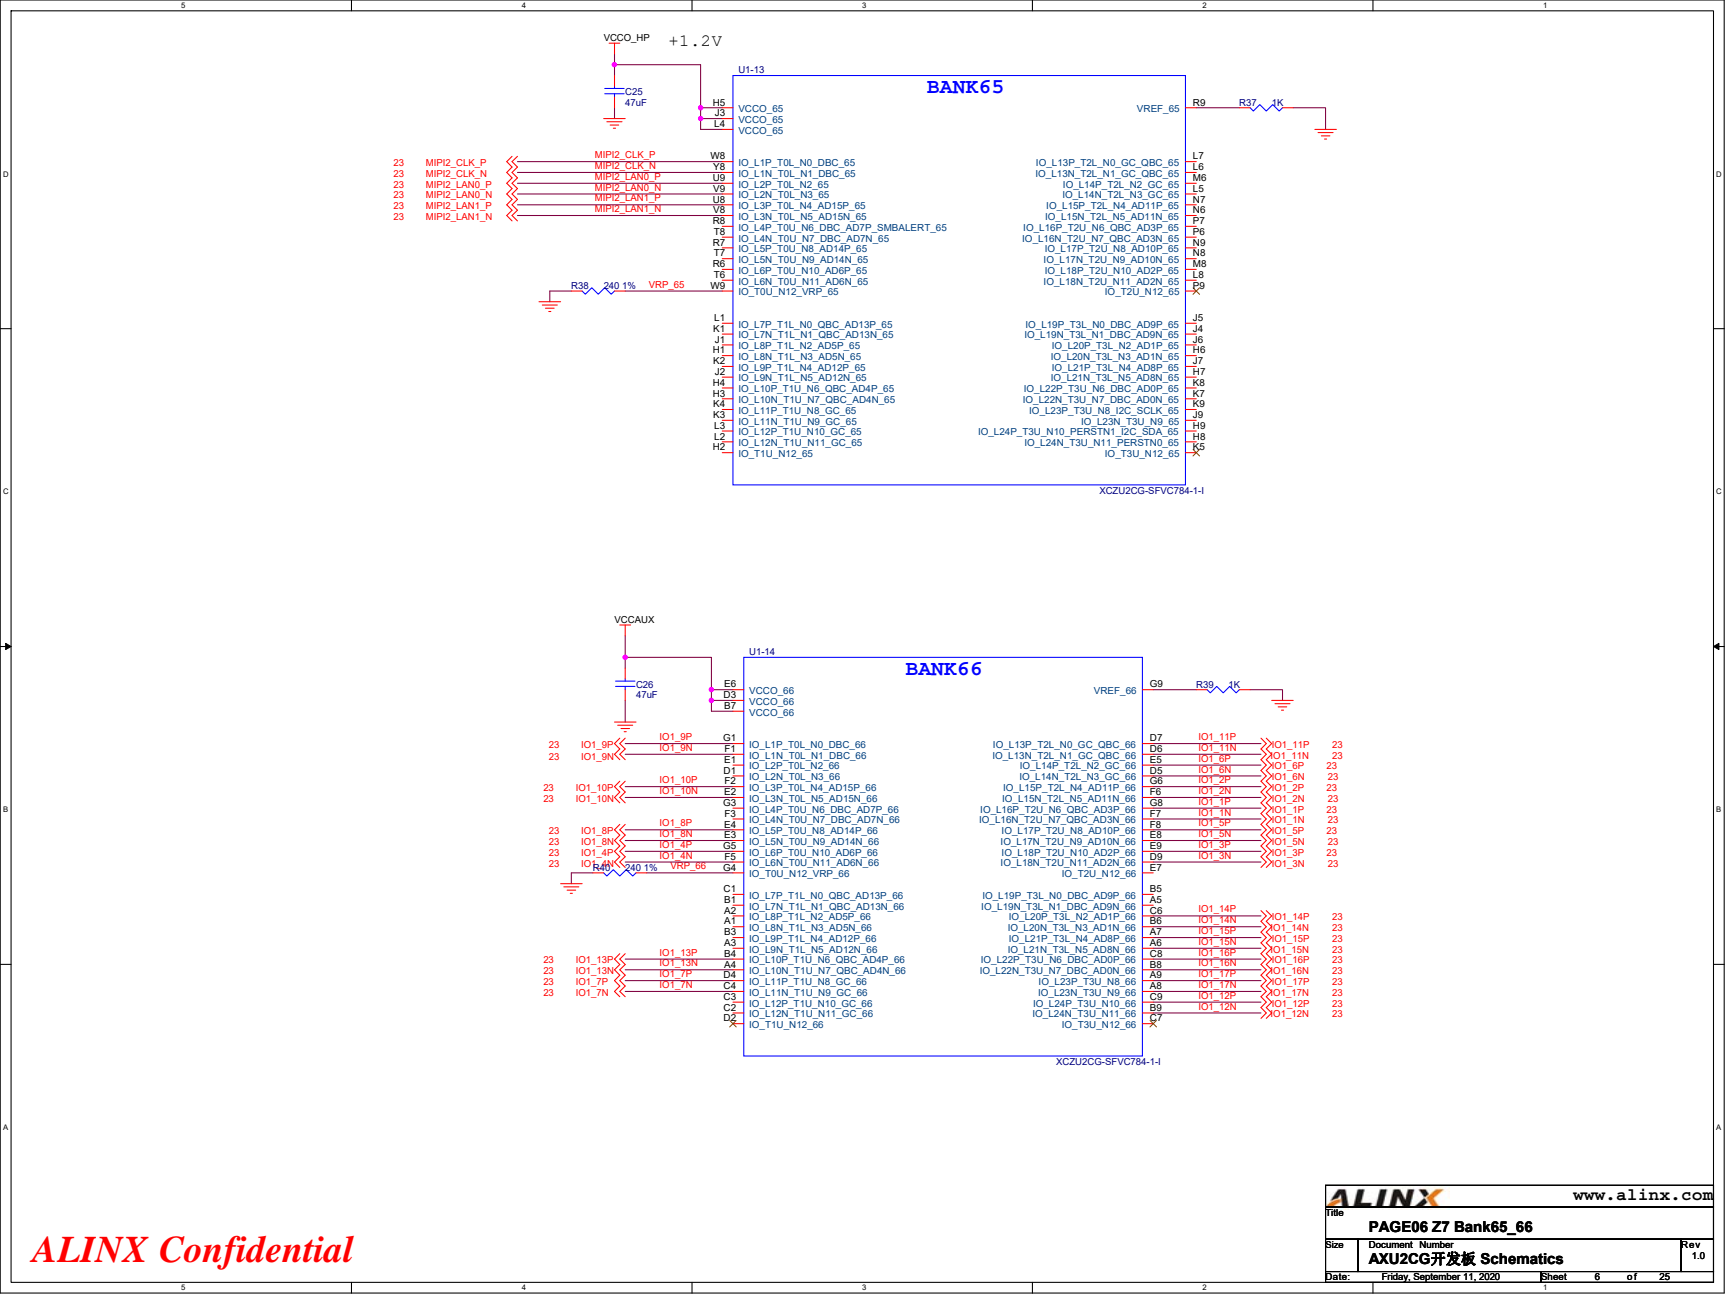
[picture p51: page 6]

# BANK505 PS MGT

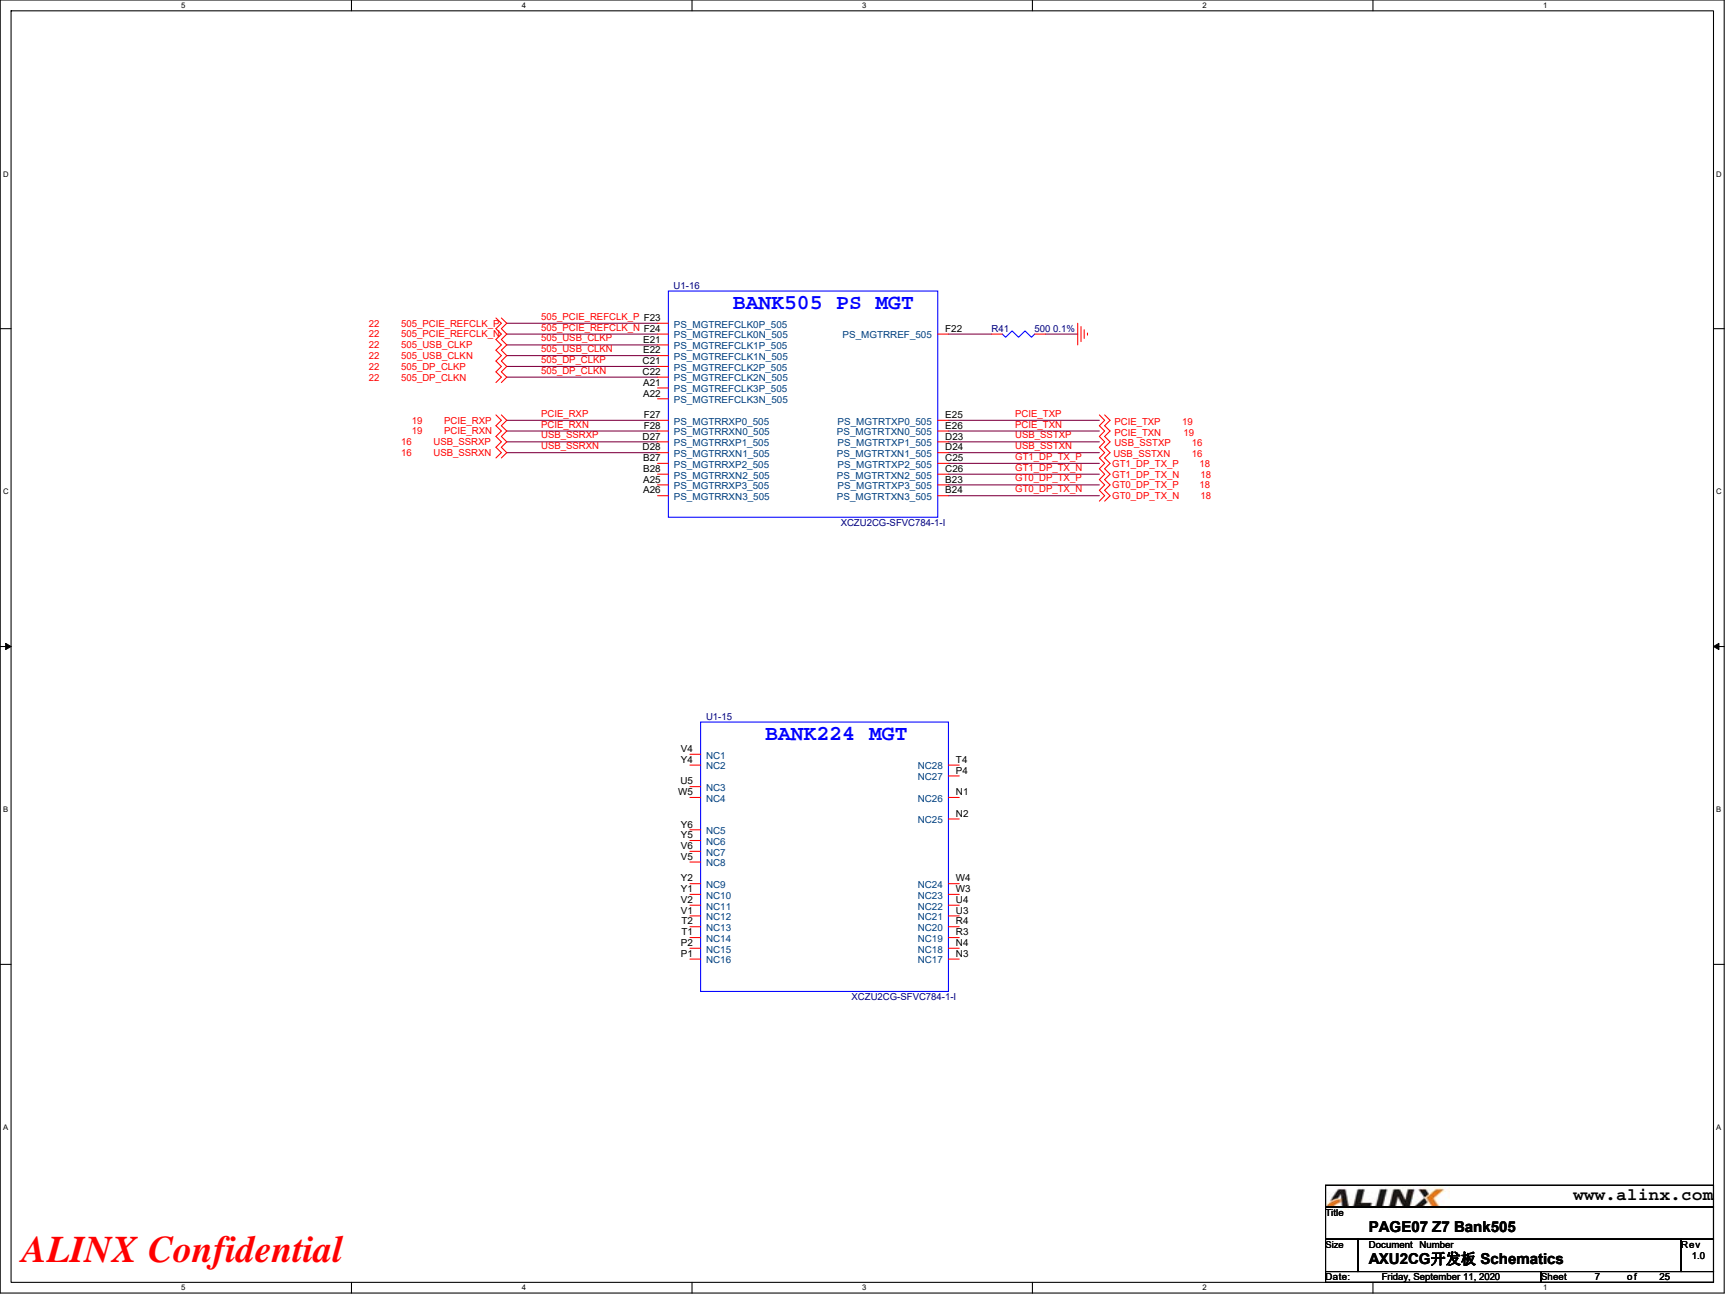
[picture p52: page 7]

1.2V
1.2V

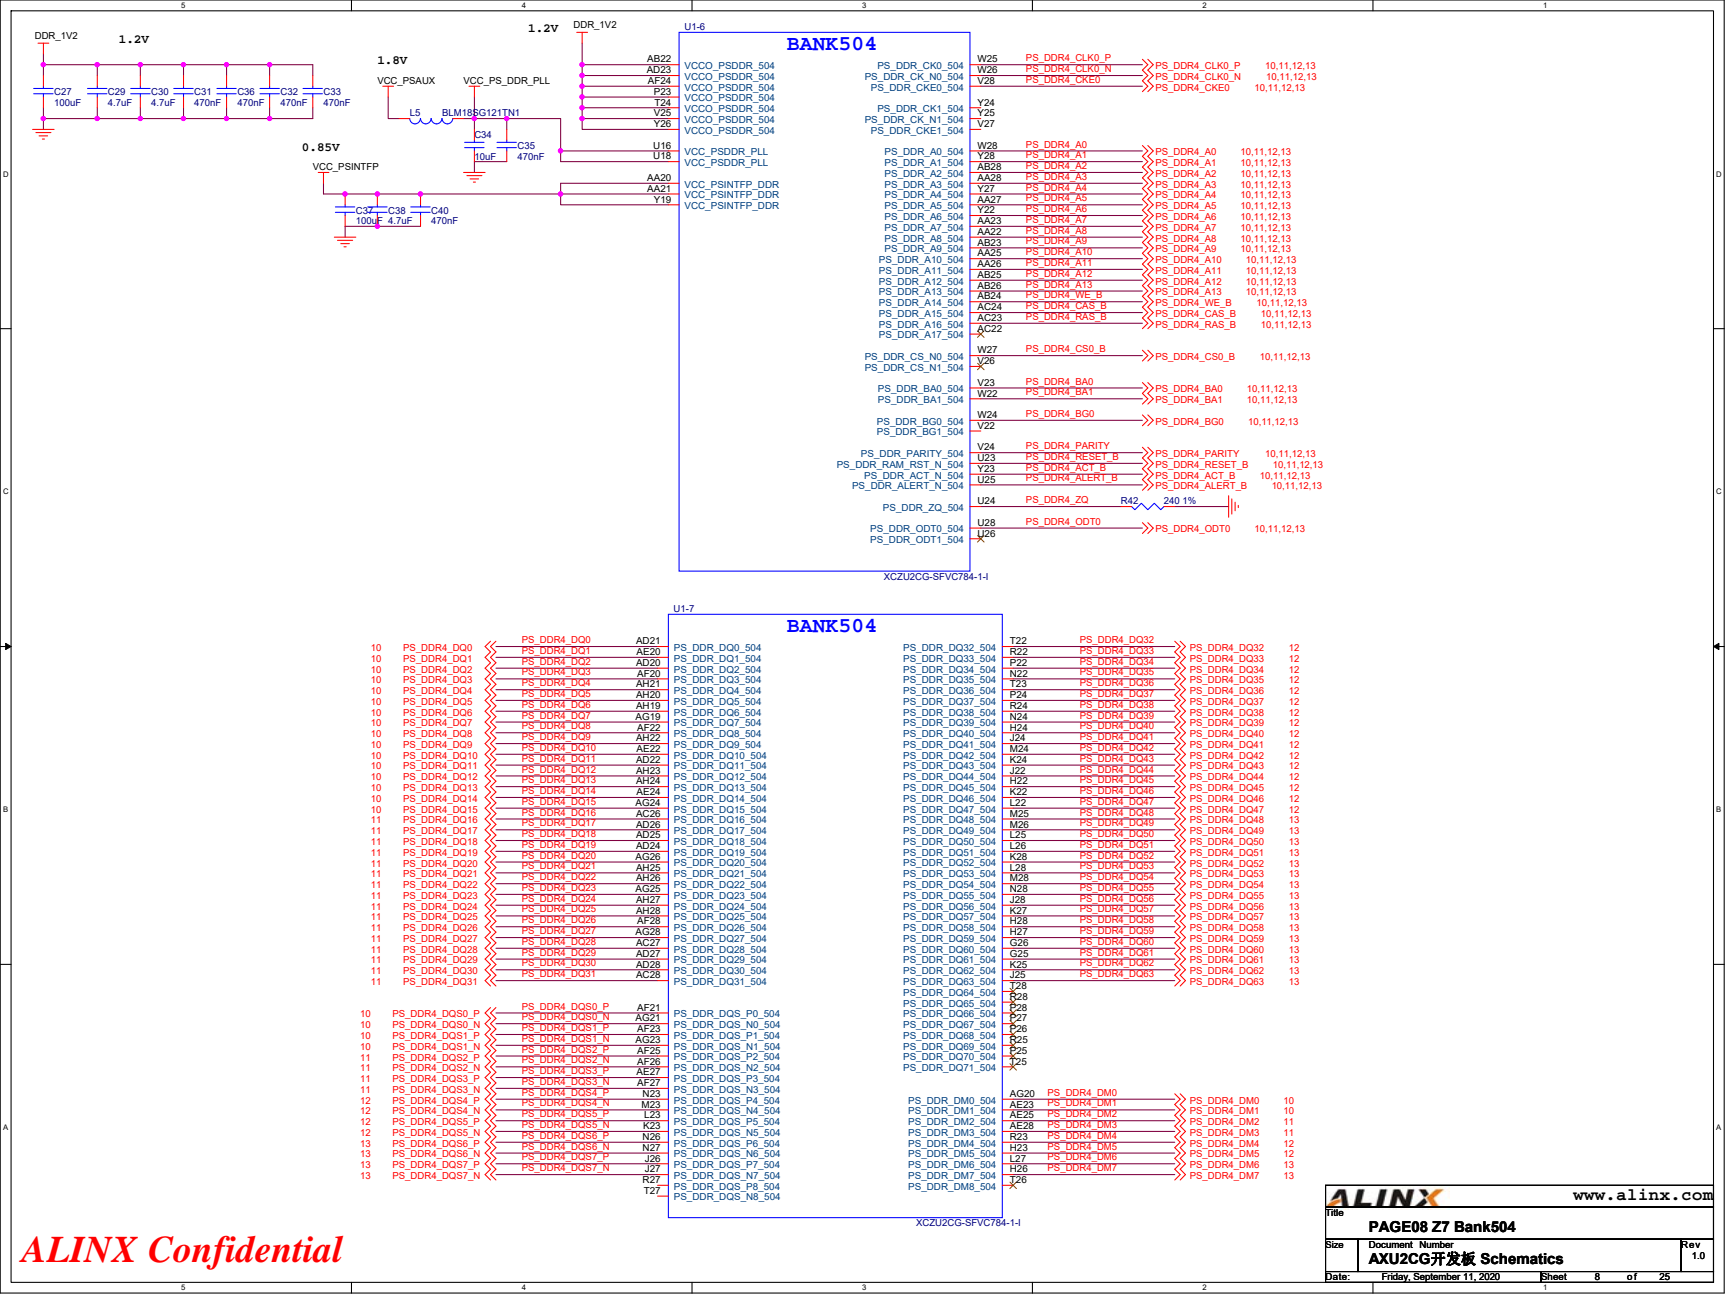
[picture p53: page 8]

0.85V

0.85V

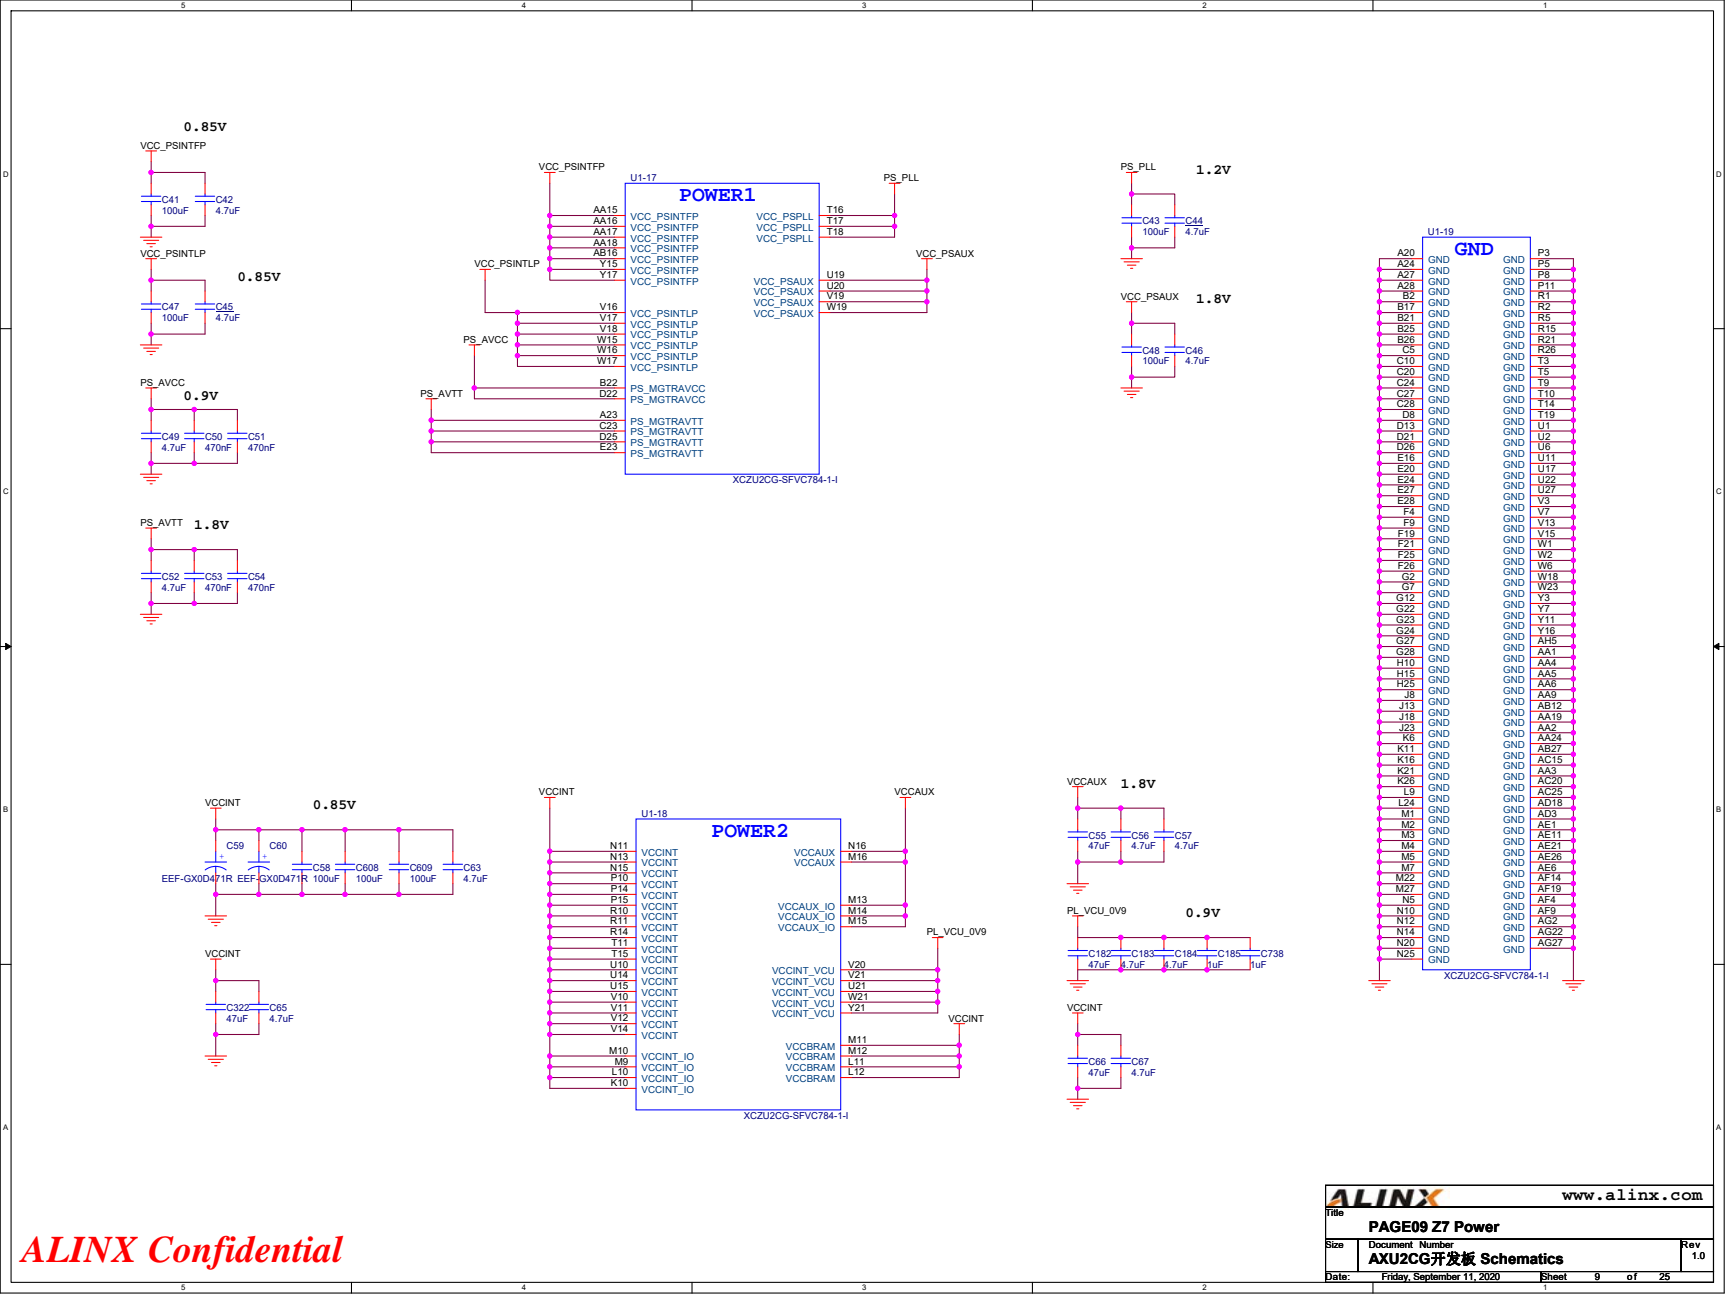
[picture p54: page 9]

1.2V

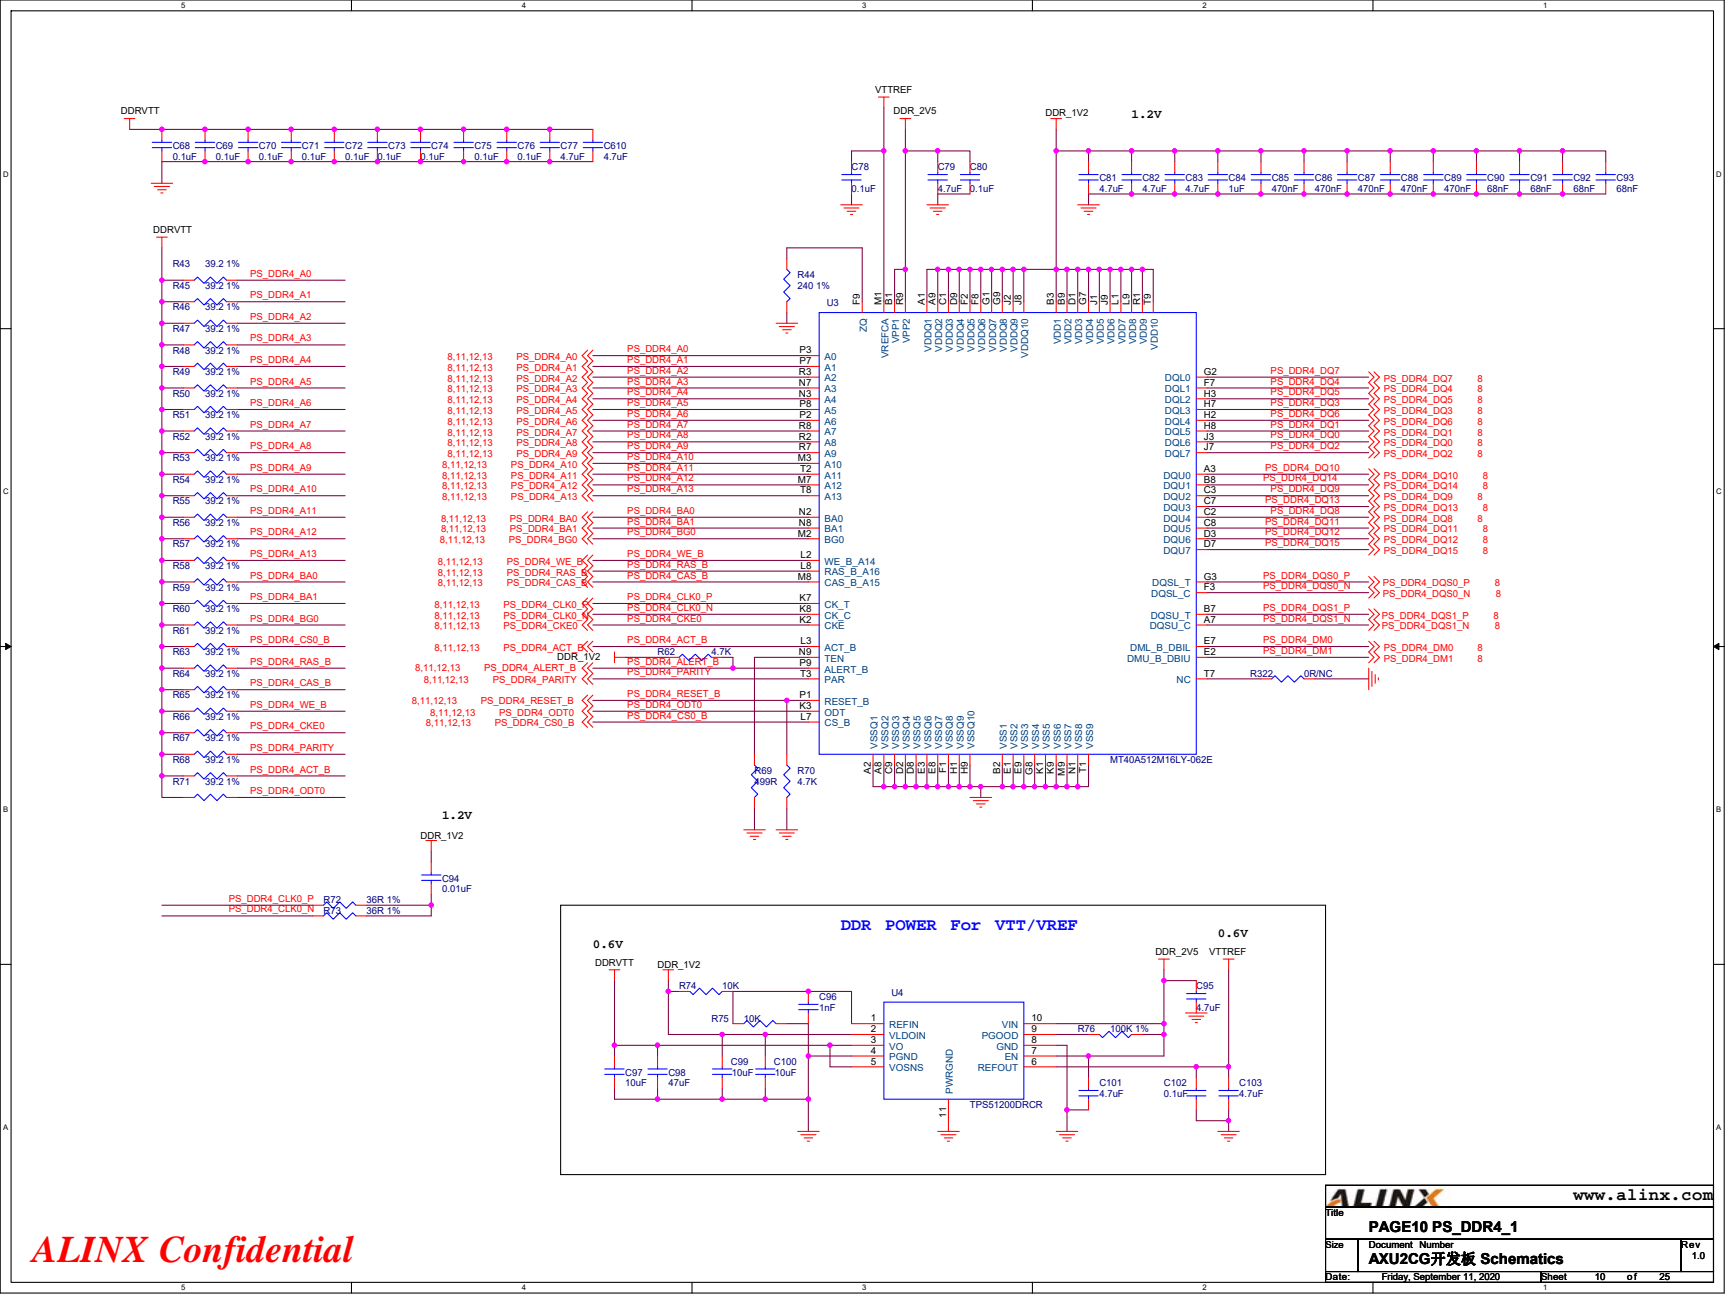
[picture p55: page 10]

1.2V

1.2V

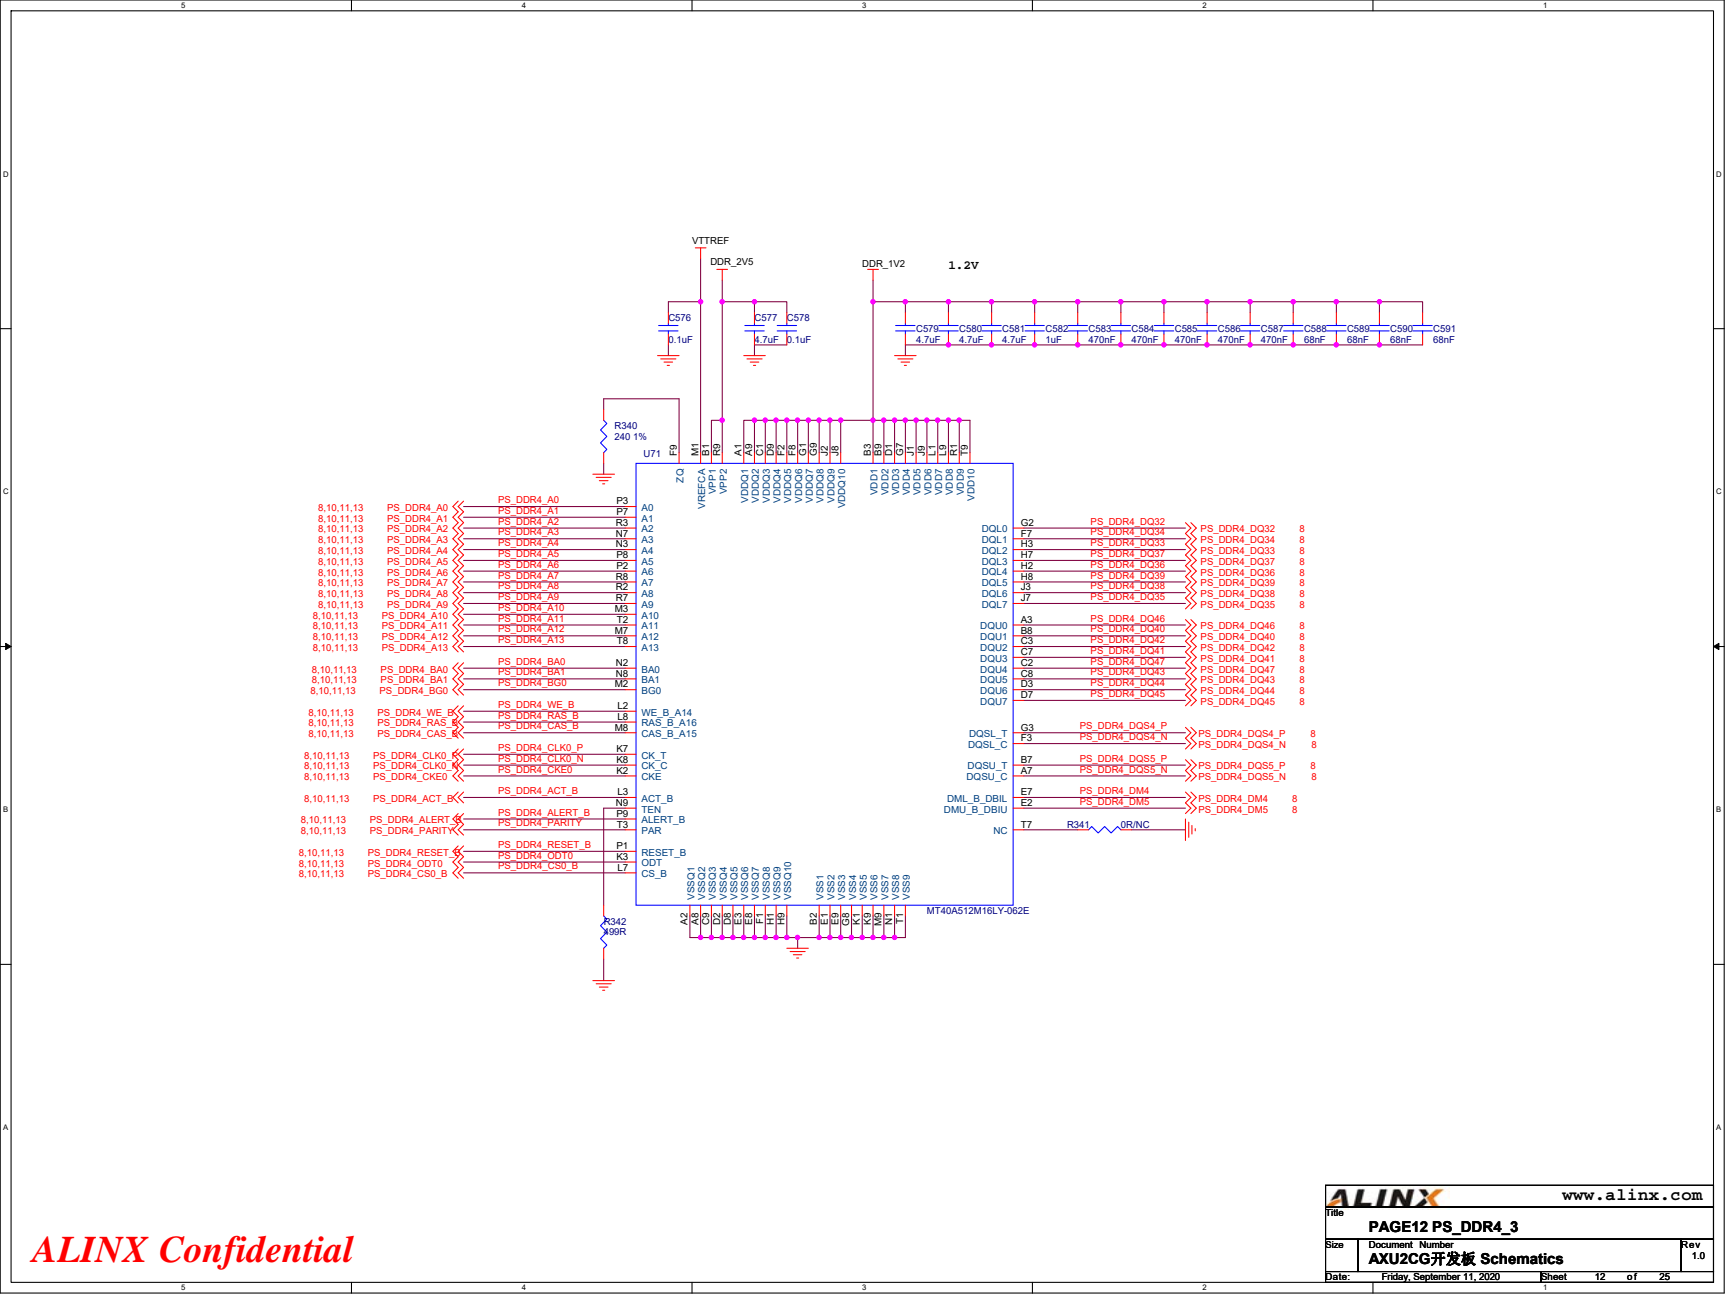
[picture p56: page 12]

1.2V

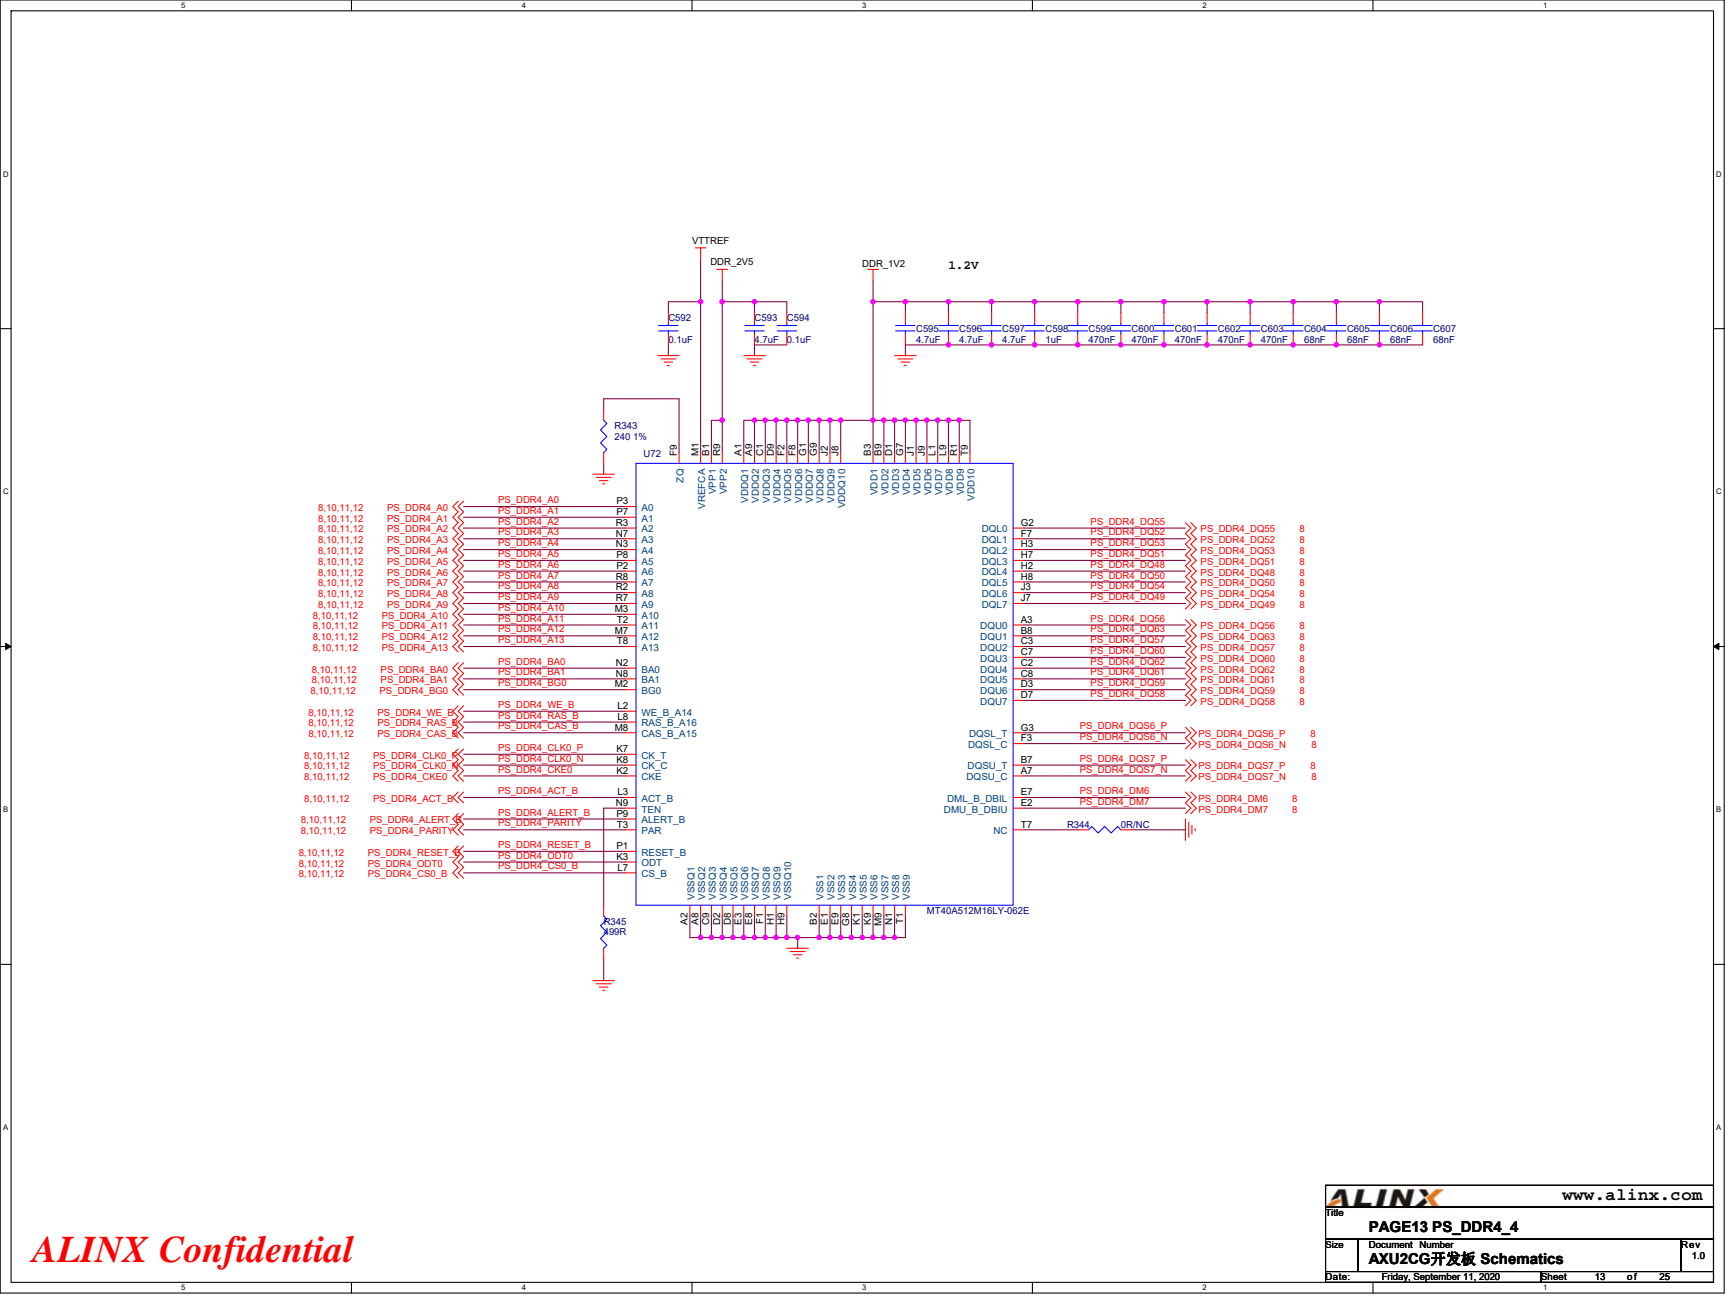
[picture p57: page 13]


1.2V

# Power Sequence: 3.3V ---> 1.2V


TRD1- P7

TRD1+ P4

TRD0- P3

TRD0+ P2

AXU2CG开发板 Schematics AXU2CG开发板 Schematics AXU2CG开发板 Schematics | 1.0 1.0 1.0

Friday, September 11, 2020 Friday, September 11, 2020 Friday, September 11, 2020 | 15 15 15 25 25 25


GREEN ALARM POW EN

# USB3.0 PORT1

# USB3.0 PORT3




AXU2CG开发板 Schematics AXU2CG开发板 Schematics AXU2CG开发板 Schematics | 1.0 1.0 1.0

Friday, September 11, 2020 Friday, September 11, 2020 Friday, September 11, 2020 | 19 19 19 25 25 25


AXU2CG开发板 Schematics AXU2CG开发板 Schematics AXU2CG开发板 Schematics | 1.0 1.0 1.0

Friday, September 11, 2020 Friday, September 11, 2020 Friday, September 11, 2020 | 20 20 20 25 25 25

# SD Card Connector



CLKIN_2 2 CLKIN_2B 3 CLKIN_3 7 CLKIN_3B 8 SCLK 11

SDA 12

VDDA 9


# GPO1-----BUCK1_2_PG GPO4-----BUCK4_PG


C283 | 10uF | | PVIN5 21 | CSD87381P | R177 390K

PVINLDOA2_A3 50

VCC_3V3_BUCK4 | PVINSWA1 32 | R178 9.31K 1%

VCC_PSAUX | | PVINSWB1_B2 18

POWER_EN | CTL4 62
PL_PWR_EN | CTL5 63 | BG 4

PS_AVTT | | LDOA1 9

VTT 47 | | 0.1uF | 10uF

SWB2 19 | | BG 4

VREF 53 | | CSD87381P

# 12V/2A AC Adapter

# FAN



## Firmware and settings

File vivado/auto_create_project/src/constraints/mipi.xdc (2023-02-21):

#Camera 0
set_property PACKAGE_PIN AH14 [get_ports {cam0_gpio[0]}]
set_property IOSTANDARD LVCMOS33 [get_ports {cam0_gpio[0]}]
set_property PULLUP true [get_ports {cam0_gpio[0]}]

set_property PACKAGE_PIN AH13 [get_ports cam0_i2c_scl_io]
set_property PACKAGE_PIN AE13 [get_ports cam0_i2c_sda_io]

set_property IOSTANDARD LVCMOS33 [get_ports cam0_i2c_scl_io]
set_property IOSTANDARD LVCMOS33 [get_ports cam0_i2c_sda_io]


set_property PULLUP true [get_ports cam0_i2c_scl_io]
set_property PULLUP true [get_ports cam0_i2c_sda_io]


#Camera 1
set_property PACKAGE_PIN AD15 [get_ports {cam1_gpio[0]}]
set_property IOSTANDARD LVCMOS33 [get_ports {cam1_gpio[0]}]
set_property PULLUP true [get_ports {cam1_gpio[0]}]

set_property PACKAGE_PIN AD14 [get_ports cam1_i2c_scl_io]
set_property PACKAGE_PIN AC13 [get_ports cam1_i2c_sda_io]

set_property IOSTANDARD LVCMOS33 [get_ports cam1_i2c_scl_io]
set_property IOSTANDARD LVCMOS33 [get_ports cam1_i2c_sda_io]


set_property PULLUP true [get_ports cam1_i2c_scl_io]
set_property PULLUP true [get_ports cam1_i2c_sda_io]

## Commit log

2023-03-15 add linux
    [bsp.cfg, devtool-fragment.cfg]
2023-03-15 修改project-spec/meta-user/recipes-bsp/u-boot/u-boot-zynq-scr/路径中的boot.cmd.default.initrd
2023-03-15 修改了部分截图
2023-03-15 中文文档完成，对应图片修改
2023-04-14 add hardware
    [AXU2CG_size_structure.dxf]
